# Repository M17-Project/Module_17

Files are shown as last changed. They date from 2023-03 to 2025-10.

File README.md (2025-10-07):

# Module 17
Welcome to Module 17 repository!

This project provides a standalone modem that transforms any 9600 baud capable transceiver into an [M17](https://m17project.org/) compatible radio. It is based on a STM32F4 microcontroller and is designed to run the [OpenRTX](https://openrtx.org/) firmware. Audio and PTT connectivity is given through a "Kenwood 2 Pin" compatible connector (2.5 and 3.5mm audio jacks) or an [OHIS](https://ohis.org/) connector (this is **NOT** an internet connector). Power supply of 6 to 15 volts can be applied through a 5.5/2.5mm DC plug.

<p align="center">
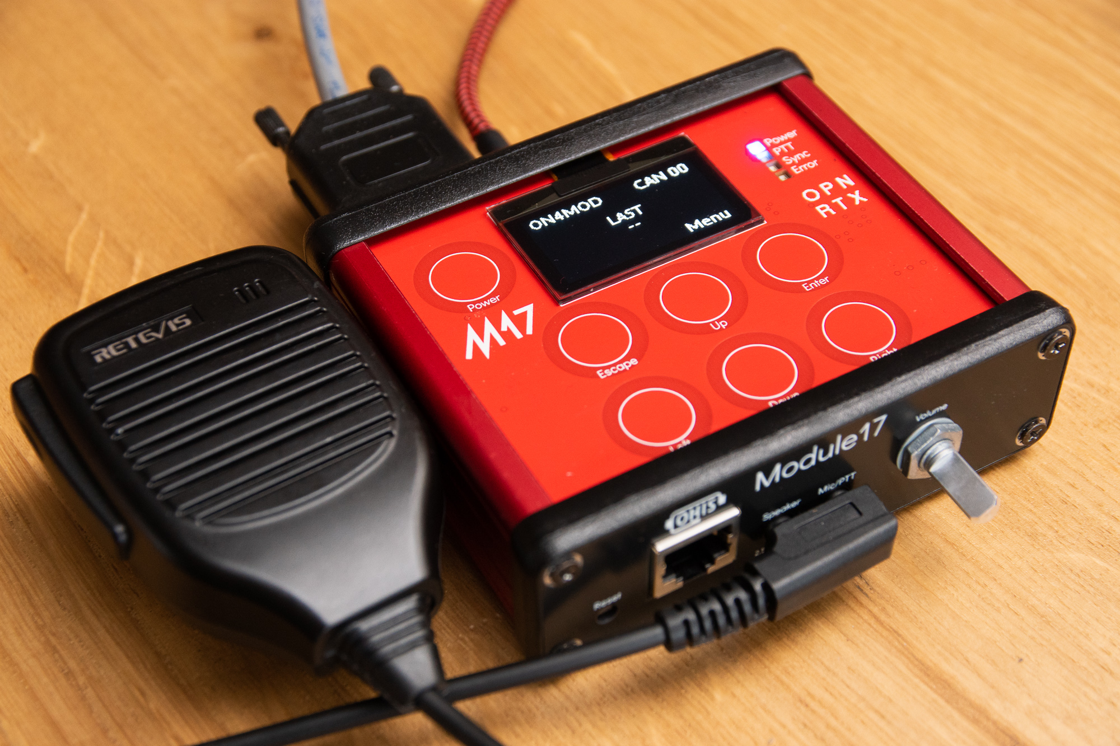
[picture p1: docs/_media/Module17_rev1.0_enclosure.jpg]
    
</p>

Several boards of various revisions have been built. The latest one is rev 1.0. This revision went through a complete board re-design, mainly to make it compatible with an aluminium extruded enclosure. It does however remain very similar in principle to the previous revisions. Other changes such as audio input and output improvements were made in this revision.

Revision 1.0 boards can be ordered partially or even fully assembled at [PCBWay](https://www.pcbway.com) with the manufacturing data in this repository. Some parts such as the digital potentiometers, the DC-DC converter inductor or the audio power amplifier may not (always) be in stock. Fortunately, they are almost always available through Mouser/Digikey. JLCPCB can acquire them through their global sourcing program if you are willing to use it.

## Versions
The current revision (rev 1.0) is available in two different versions:
- Enclosure with additional board for the user interface (called HMI, see picture above)
- Bare board (similar to how revisions 0.1d/e were used)
    <p align="center">
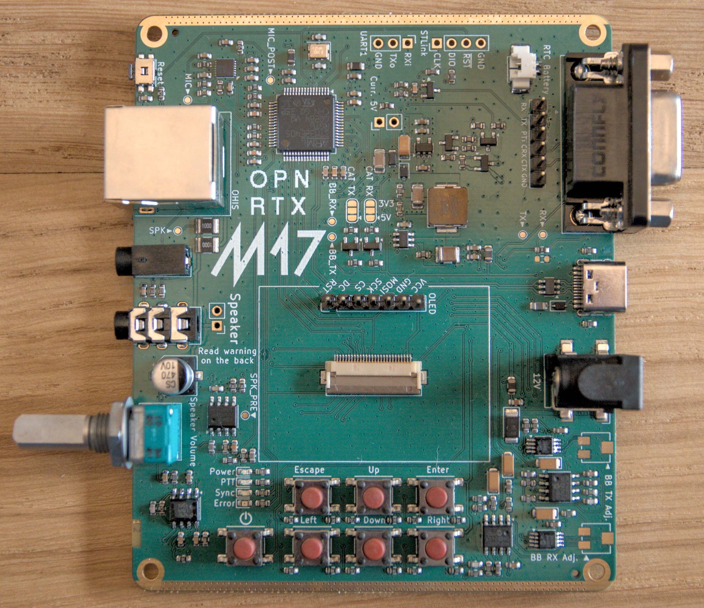
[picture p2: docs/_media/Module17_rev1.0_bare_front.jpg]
    
    </p>

The board can be switched from one version to another relatively easily. To convert a bare board to an enclosed version, the screen needs to be removed and a few additional PCBs need to be ordered (see the [Ordering guide](./docs/order.md)).

You can of course always 3D-print an enclosure for your bare board.

## Getting Started
The very first step is to get a board. The board is not available for sale yet. Head over to the [Ordering guide](./docs/order.md) to get a board. If you want to assemble the board with the designed enclosure and HMI, follow the instructions from the [enclosure instructions](./docs/enclosure.md).

Otherwise, if you just obtained a Module17 board, you may want to:

1. Flash it with OpenRTX, the officially supported firmware [Details](./docs/flashing.md)
2. Configure OpenRTX settings [Details](./docs/quickstart.md#configure-openrtx)
3. Connect the board to a radio. The DE-9 connector at the top of the board can be used to connect Module17 to a 9600baud radio. The pinout is shown in the table [here](./docs/features.md#de-9-connector).
4. Adjust the baseband levels for your specific transceiver [Details](./docs/quickstart.md#adjusting-the-baseband-levels)

A list of tested transceivers is [here](https://wiki.m17foundation.org/index.php?title=Radio_compatibility_list).

## Building the firmware yourself
Building instructions are available [at the OpenRTX project's website](https://openrtx.org/#/compiling).

## Features
The board contains many features, some of which you may never use. Here is a list:
- [Rev 1.0](./docs/features.md)
- [Rev 0.1d/e](../1e29440208ae519b9b4e89094e34ecb27943ad3d/README.md#usage-rev-01de)

## Acknowledgments
This project is inspired by David Rowe's [SM1000](https://www.rowetel.com/wordpress/?p=3125) "smart microphone".

## License
Module 17 hardware is licensed under the [CERN Open Hardware License - Weakly Reciprocal](https://ohwr.org/cern_ohl_w_v2.txt)

Module 17 is certified by OSHWA under ID BE000019.

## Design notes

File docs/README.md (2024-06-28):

# Module 17
Welcome to Module 17!

This project provides a standalone _smart microphone_ that transforms any 9600 baud capable transceiver into an [M17](https://m17project.org/) compatible radio. It is based on a STM32F4 microcontroller and is designed to run the [OpenRTX](https://openrtx.org/) firmware. Audio and PTT connectivity is given through a "Kenwood 2 Pin" compatible connector (2.5 and 3.5mm audio jacks) or an [OHIS](https://ohis.org/) connector (this is **NOT** an internet connector).

:size=25%

Several boards of various revisions have been built. The latest one is rev 1.0. This revision went through a complete board re-design, mainly to make it compatible with an aluminium extruded enclosure. It does however remain very similar in principle to the previous revisions. Other changes such as audio input and output improvements were made in this revision.

Revision 1.0 boards can be ordered partially or even fully assembled at [JLCPCB](https://www.jlcpcb.com) with the manufacturing data in this repository. Some parts such as the digital potentiometers, the DC-DC converter inductor or the audio power amplifier may not (always) be in stock at JLCPCB. Though they are almost always available through Mouser/Digikey. JLCPCB can acquire them through their global sourcing program if you are willing to use it.

## Acknowledgments
This project is inspired by David Rowe's [SM1000](https://www.rowetel.com/wordpress/?p=3125) Codec2 smart mic and shares some of its circuitry. The analog baseband filtering is inspired by the [MMDVM_RPT_Hat](https://github.com/mathisschmieder/MMDVM_RPT_Hat) and is a simplified version of F0DEI's original filter design that is used with great success at many MMDVM repeater sites.

## License
Module 17 is licensed under the [TAPR Open Hardware License](https://tapr.org/the-tapr-open-hardware-license/)

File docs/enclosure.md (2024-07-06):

## Enclosure

Module17 revision 1.0 is designed to be compatible with Hammond enclosures (model 1455L801).

### Hardware needed
To use Module17 with the enclosure, you need:
* One Module17 revision 1.0
* One Hammond 1455L801 enclosure (you do not need the sliding plate or the end panels)
* One Module17 HMI board revision 1.0
* One flex 26 pins flex connector (FFC cable, pitch of 0.5mm, connectors thickness of 0.3mm, length of minimum 50mm, edge connectors on the same side)
* One of each side panel PCB
* One 128x64 OLED screen (1.54" diagonal, SSD1309 driver)
* Optional: 8 self-tapping screws with non-tapered head (one standard that might fit is DIN 7500 with size M3.5). This is optional as the screws that came with the enclosure can be used, but the side panels PCBs do not have tapered holes so the fit will not be perfect.

### Assembly instructions
1) First open the enclosure, removing the end panels and removing the sliding plate.
2) Connect the mainboard to the HMI board using the FFC cable: one end of the cable goes in the FFC connector placed below the screen connector, the other end in the FFC connector on the left of the HMI board (when facing the side with the components). The connectors of the cable must face the boards for each connector.
3) Carefully slide the mainboard and the HMI inside the enclosure. The mainboard goes in the lowest position. The HMI board slides at the place where the sliding place removed at step 1 was located.
4) Insert the side panels PCBs inside the plastic bezels that came with the enclosure.
5) Place the side panels on the assembly and screw then in place.
6) Stick the rubber feets that came with the enclosures on the bottom of the assembly.

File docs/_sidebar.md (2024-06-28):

* [Home](/)
* [README](./README.md)
* [Flashing](./flashing.md)
* [Features](./features.md)
* [Ordering](./order.md)
* [Enclosure](./enclosure.md)
* [Revisions](./revisions.md)

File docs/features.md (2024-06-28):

# Features (rev 1.0)

<p align="center">
    
</p>

## Power supply

The modem can be supplied with:
- a 6..15V source via the DC plug (left of the USB-C socket) or pin 9 of the DE9 connector (upper right hand side),
- 5V through the USB-C connector (in the middle of the right side)
Both inputs can be used at the same time.

When power is supplied through the barrel jack (DC plug) the board can be powered on using the power button and powered off in the menu of the board (Enter -> Select Shutdown -> Enter)

When power is supplied through the USB-C socket, the board is always powered on and cannot be powered off.

## DE-9 connector

The DE-9 connector at the top of the board can be used to connect Module17 to a 9600baud radio. The pinout is shown in the table below.

| Pin | Function | Direction | `CT-167` cable wire color |
|---|:---:|---|---|
| 1 |  unused (floating) |  -- | |
| 2 |  baseband output (towards radio) |  output |  brown |
| 3 |  CAT-RX |  input | |
| 4 |  CAT-TX |  output | |
| 5 |  radio PTT |  output, open-drain, low-active  |  red |
| 6 |  baseband input (from radio) |  input |  orange |
| 7 |  unused (floating) |  -- | |
| 8 |  ground |  -- |  black, thick |
| 9 |  12V input | input (supply) | |

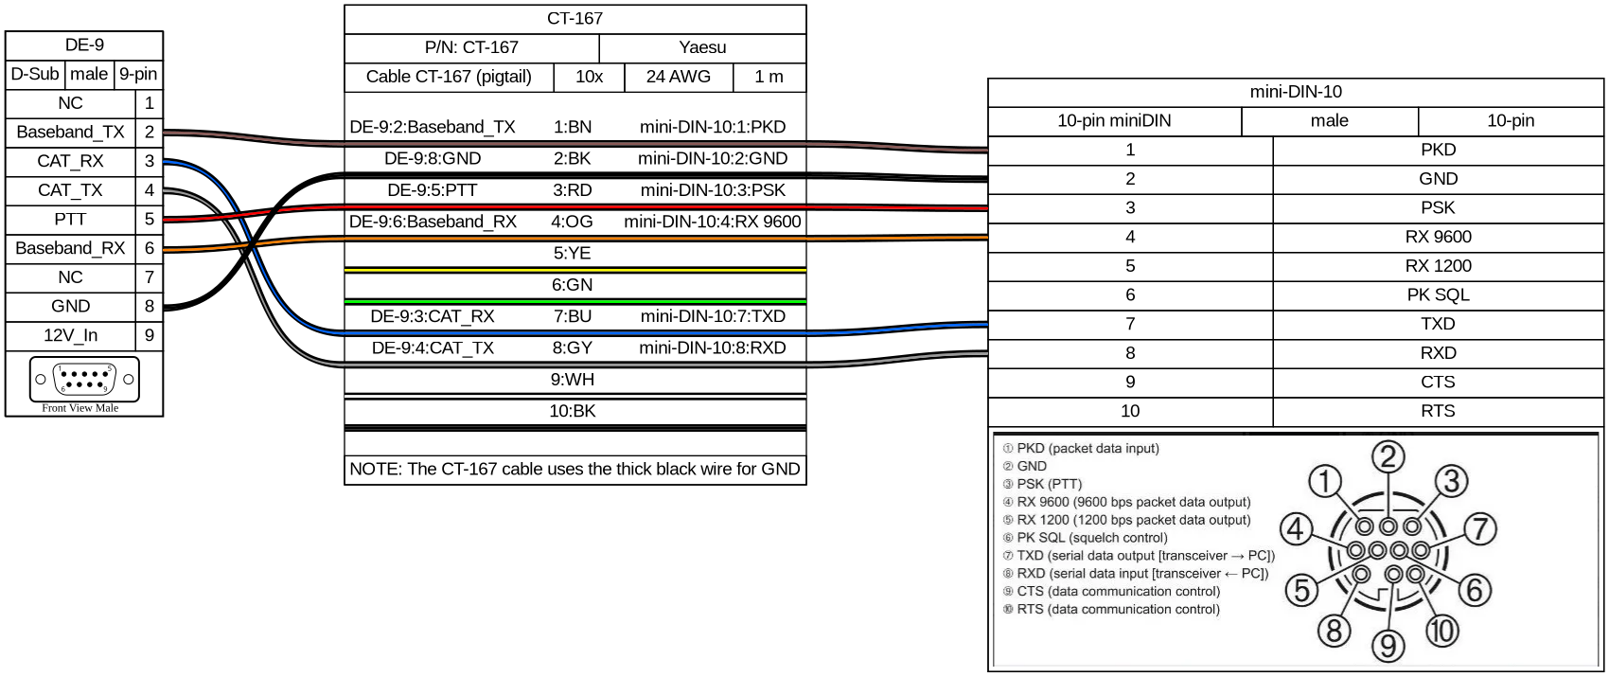
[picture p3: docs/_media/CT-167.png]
CT-167 Wiring :size=75%


Additionally, there is a 2.54mm pin header just next to the DE-9 connector that can be used for convenient access to the baseband, PTT and CAT signals. Pin 9 doesn't have to be used, it only provides an alternative way for supplying power to the board.  

## Kenwood mic-speaker connector

On the left hand side of the board, there is a Kenwood-type connector. The pinout is standard and most microphone-speakers should be compatible with Module17. In particular, the microphone-speakers from Baofeng, TYT and Retevis have been tested and are compatible.

## OHIS connector

The board provides an OHIS connector if you want to use other audio devices than classical microphone-speakers. The connector does not provide the optional 5V output. See [OHIS Website](https://ohis.org/) for more information.

## Volume knob

The volume knob is at the bottom left part of the board. As the name suggests, it is used for audio volume setting. 

## Transmission/reception

At idle, the device will look for valid M17 signal in the baseband. If there is a valid signal detected carrying voice data, it will be decoded and sent to the speaker outputs at the Kenwood  connector. There is also an additional, unpopulated, 2-pin speaker connector in the left part of the modem. It can be used to connect an external >=8ohms speaker.
Transmission is triggered by the PTT key of the mic-speaker or OHIS connector. A valid baseband signal along with a PTT signal is then sent to the radio.

## Baseband tuning

In order to support as many transceivers as possible, the baseband level requires tuning to drive your transceiver with the correct signal level. The process depends on the variant of your board. If you have the digital potentiometers fitted, the adjustment is done in OpenRTX. If you have the multiturn potentiometers fittes, you will need to adjust them using a small screwdriver. The detailed procedure is explained

## CAT control

The hardware is ready for CAT signal to control a transceiver using the modem but OpenRTX does not implement it yet. It can not be used out of the box and you would need to implement it manually to use it. There is hardware support for logical level selection (3.3V or 5V). (June 2024)

## RTC Battery

The hardware has a microblade connector to enable you to connect a 3V lithium battery to supply the real time clock inside the microcontroller. OpenRTX does not implement RTC management for Module17 yet. (June 2024)

## Test points

Multiple test points are available on the PCB to allow you to check the values of all the various signals (audio, baseband, power supplies, ...). Those are labeled with the signal they expose.

## Debug port

A debug port is available on the top part of the modem. It exposes the signals for the ARM SWD port of the microcontroller.

## Serial port

A serial port is exposed on the top part of the modem. It allows you to, for example, add a GPS chip (there is currently no software support for GPS). (June 2024)

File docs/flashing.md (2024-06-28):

## Flashing

### Entering DFU mode
To flash the board, you need to put it in DFU mode. The procedure to do so will depend whether you use the HMI board or not.

#### Using the bare modem board (rev 1.0)
Hold the "Escape" (upper left) button down while pressing the reset switch (upper left corner of the board) or plugging in the USB cable.

#### Using the HMI and enclosure (rev 1.0)
First put the switch on the rear of the device to the "FW Update" position then either plug in the USB cable or press the reset switch (bottom left corner of the front face of the device). When the device is in DFU mode, you can then put the switch on the rear of the device back to the "Run" position.

#### Using the bare modem board (revisions 0.1a to 0.1e)
Hold the "Escape" (upper left) button down while pressing the reset switch (left side of the board, above the kenwood connectors) or plugging in the USB cable.

### Linux
To flash, you first need to put the device in DFU mode (see above).

You need `dfu-util` 0.11 to start the process. `dfu-util` installation instructions are [here](https://dfu-util.sourceforge.net/build.html). It is recommended to use the most recent version - built from source.

For your convenience, a pre-built binary is available [here](https://files.openrtx.org/nightly/) and [here](https://openrtx.schinken-radio.de/nightly/). The name of the file is `openrtx_mod17_wrap`.
You can then follow standard [OpenRTX](https://github.com/OpenRTX/OpenRTX)
flashing instructions for the "mod17" target if you have dfu-util
installed:<br>
`dfu-util -d 0483:df11 -a 0 -D openrtx_mod17_wrap -s 0x08000000`

Once flashing is complete, reset the board to boot into the newly flashed application. If there are any errors while flashing, make sure there's a valid udev rule available for the Module17. Download the [udev](https://github.com/OpenRTX/OpenRTX/blob/master/99-openrtx.rules) file and then run the following commands:<br>
`sudo cp 99-openrtx.rules /etc/udev/rules.d`<br>
`sudo udevadm control --reload-rules`.

### Windows
To flash, you first need to put the device in DFU mode (see above).

Be sure that you have WinUSB installed for your DFU device. You can use [Zadig](https://zadig.akeo.ie/). After the Module17 is connected and in DFU mode, select it from the list in Zadig, then install the driver.

- Download the [dfu-util-0.11-binaries.tar.xz dfu-util binary for Windows](https://dfu-util.sourceforge.net/releases/) and unzip.
- Download the `openrtx_mod17_wrap` file, it's available [here](https://files.openrtx.org/nightly/) and [here](https://openrtx.schinken-radio.de/nightly/).
- Navigate to `{extraction_location}\dfu-util-0.11-binaries\win64` (or `win32`) and copy the wrap file there. Example path: `C:\Users\SP5WWP\Desktop\dfu-util-0.11-binaries\win64`.
- Run the command prompt (`cmd`) as administrator and change the working directory with `cd {extraction_location}\dfu-util-0.11-binaries\win64`.
- Run the following command: `dfu-util -d 0483:df11 -a 0 -D openrtx_mod17_wrap -s 0x08000000`
- After the flashing is complete, close the command prompt and reset the device.

### Building the firmware yourself
Building instructions are available [at the OpenRTX project's website](https://openrtx.org/#/compiling).<br>

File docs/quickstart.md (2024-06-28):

# Quickstart guide

You have successfuly [flashed](./flashing.md) your Module17 and want to get started? This quickstart guide explains how to get on the air for the first time.

## Configure OpenRTX

The first thing to do is to configure OpenRTX. The only real change needed is to encode your callsign in the device. For that:
- Press "Enter"
- Select "M17" and press "Enter"
- Select "Callsign" and press "Enter"
- Input your callsign using "Up"/"Down" to select the correct letter and "Left/Right" to muve the cursor to the left/right. 
- Press "Enter" once you are done.

## Adjusting the baseband levels

### Check your transceiver compatibility

[This wiki page](https://wiki.m17project.org/radio_compatibility) contains a non-exhaustive list of the known compatible transceiver. Check if yours is in the list. If it is not, you will need to test it. Please submit an issue [here](https://github.com/M17-Project/wiki/issues) once you are done testing your radio.

### Adjust the baseband level

The precise level of the baseband signal needs to be tuned to your radio's requirements. You will need to adjust both the RX and TX levels separately.

Depending on the variant of your board, the level tuning is done with digital potentiometers or multiturn potentiometers. 

The multiturn potentiometers need to be adjusted with a small screwdriver.

The digital potentiometers need to be adjusted from within OpenRTX. For that, power-up your Module17 and:
- Press "Enter"
- Select "Settings" and press "Enter"
- Select "Module17" and press "Enter"
- Select the baseband signal you want to adjust. Adjust the level using the "Left"/"Right" keys.

#### Adjusting TX level

The most reliable way to tune the TX baseband signal level is using SDR++ and an SDR receiver (like an RTL-SDR). 

- Connect your Module17 to your radio
- Add an M17 demodulator module to your SDR++ interface and tune it to the frequency of your radio
- In the m17_decoder module you added, tick the "Show Reference Lines" box
- While pressing the PTT, have a look at the symbols graph of the m17\_decoder module and adjust the baseband TX level until the blue dots line-up with the gray lines in the background
- When the baseband level is properly adjusted, the m17_decoder should correctly decode your signal. If it does not, check your TX baseband polarity. If it still does not work, your radio may be incompatible.

#### Adjusting RX baseband level

A proper RX baseband level adjustment is not as crucial as for TX baseband. You should set it so that the peak-to-peak voltage of the RX baseband signal (on testpoint labeled `BB_RX`) is right under 3.3V. Anything above that means that the signal will be saturating in the MCU. Anything below that means that you are not using the full dynamic range of the analog-to-digital converter.

In order to measure the level on the testpoint, you can use an oscilloscope if you have one. You can also use a digital multimerer (but pay attention that the value displayed will **NOT** be the peak-to-peak voltage but the RMS voltage; in that case aim vor an RMS value of 1.1V). You should measure this voltage while receiving an M17 baseband signal.

If the signal is tuned to the proper level but the board cannot demodulate the incoming signal then check the RX baseband signal polarity. If it still does not work, then your radio may be incompatible.

### Adjust the baseband polarity

The polarity of the baseband signal may need to be modified depending on your specific radio. If your radio is listed in the compatibility list linked above then you can re-use the settings from that list. Otherwise you will need to try both settings for RX and TX to check which one works.

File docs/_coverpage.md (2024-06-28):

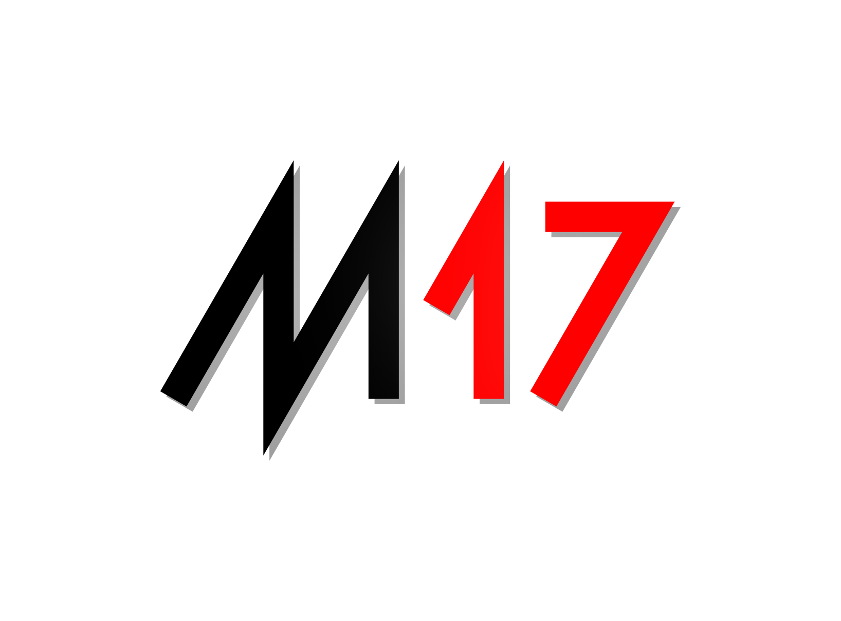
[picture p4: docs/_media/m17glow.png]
:size=25%


# Module 17 <small>1.0</small>

> A smart-mic for the M17 Protocol

[Github](https://github.com/M17-Project/Module_17)
[Get Started](README)

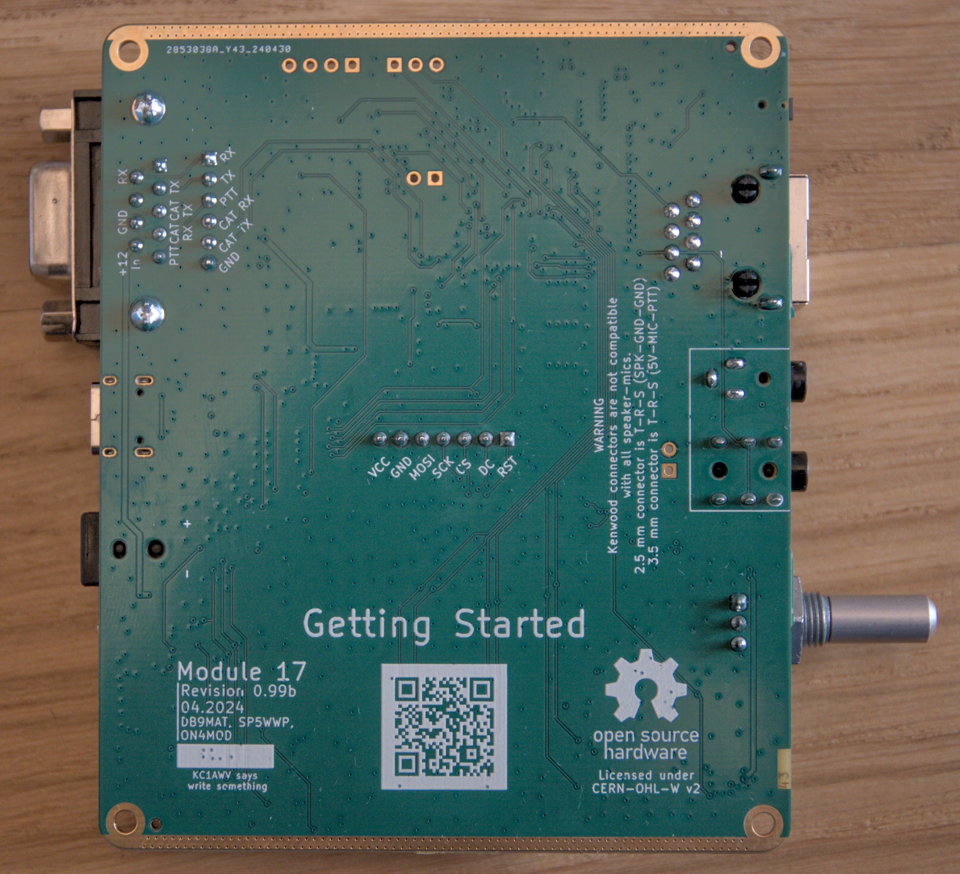
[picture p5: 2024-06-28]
docs/_media/Module17_rev1.0_bare_back.jpg

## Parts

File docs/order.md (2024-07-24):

# Ordering guide for Module17

This guide explains how to order Module17 boards on JLCPCB. JLCPCB is one of the websites that provides PCB assembly services to customers in small series. Other websites do provide the same services and you would have to adapt those instructions (though the general process will stay the same).

The process to order the board is quite simple :
- You upload the manufacturing files to the manufacturers website
- You configure the order to produce the boards correctly
- You upload a list of components and their positions on the board
- You fix the components placement and the parts numbers
- You receive the boards (and solder a few additional components if needed)

The first four steps have to be repeated for each board that you want to order. You will usually order the mainboard in all cases. You can additionally order the HMI and front/back panels if you want to use the [designed enclosure](./enclosure.md). The side panels only require the first two steps as they do not contain any components.

If you want to use the bareboad version with only the mainboard, you will also need an additional screen from Waveshare ([Waveshare 18179](https://www.waveshare.com/1.3inch-oled-module-c.htm))

## Production files

You will first need to locate the production files as you will have to upload them on JLCPCB website. 

* Mainboard files are located in [`Module_17/hardware/mainboard/production/`](../hardware/mainboard/production):
    * [`Module17_Rev_1.0.zip`](../hardware/mainboard/production/Module17_Rev_1.0.zip) contains the gerber files (the PCB fabrication files)
    * [`bom_digipot.csv`](../hardware/mainboard/production/bom-digipot.csv) contains the bill-of-materials, the list of components needed
    * [`positions_digipot.csv`](../hardware/mainboard/production/positions-digipot.csv) contains the position of all the components to assemble on the board (also called CPL file)

    Note: Both the BOM and positions files have a `-multiturn` variant that is to be used if you want to use the multiturn potentiometers for the baseband tuning instead of the digital potentiometers (see [below](./order.md#mainboard))

* HMI files are located in [`Module_17/hardware/HMI/production/`](../hardware/HMI/production):
    * [`Module17_HMI_Rev_1.0.zip`](../hardware/HMI/production/Module17_HMI_Rev_1.0.zip) contains the gerber files (the PCB fabrication files)
    * [`bom.csv`](../hardware/HMI/production/bom.csv) contains the bill-of-materials, the list of components needed
    * [`positions.csv`](../hardware/HMI/production/positions.csv) contains the position of all the components to assemble on the board (also called CPL file)

* Side panels files are located in [`Module_17/hardware/side_panels/production/`](../hardware/side_panels/production):
    * [`Module17_HMI_Front_Panel_Rev_1.0.zip`](../hardware/side_panels/production/Module17_HMI_Front_Panel_Rev_1.0.zip) contains the gerber files for the front panel
    * [`Module17_HMI_Back_Panel_Rev_1.0.zip`](../hardware/side_panels/production/Module17_HMI_Back_Panel_Rev_1.0.zip) contains the gerber files for the back panel

## Ordering

For each board that you want to order, follow the following instructions. Additional, **important** board-specific instructions are provided below. 

- Navigate to [https://cart.jlcpcb.com/quote](https://cart.jlcpcb.com/quote) 
- Click on "Add gerber file" and upload the zip file containing the gerber files (PCB fabrication files)
- Once the files are uploaded, ensure the correct settings are selected for the board you are ordering (the settings differ for the main board, HMI and side panels, see below)
- If you selected the "PCB Assembly" option, click next, otherwise, click "Save to cart" and you are done

The following instructions are for PCB Assembly:
- Select the "Bill of Materials" tab above the picture of the PCB
- Click "Add BOM File" and select the `bom.csv` file corresponding to the board you are ordering
- Click "Add CPL File" and select the `position.csv` file corresponding to the board you are ordering
- Click "Process BOM & CPL"
- ***VERY IMPORTANT:*** check that the correct components are selected by JLCPCB. You will most probably need to do a few adjustments (see below for board-specific instructions)
- Click Next. If JLCPCB shows a pop-up saying "Project has unselected parts" click "Do not place". If you did not intend to order the board with these parts then it is alright. Otherwise, you will need to order those parts elsewhere and solder them by hand once you received the partially assembled boards
- If JLCPCB then says that "The system detects component that may be offset from the PCB" click "Ok"
- Carefully check that all the components on the board are placed correctly. See the instructions below for an example picture
- Click "Next" and check the overview of you order
- Click "Save to Cart"

# Board-specific instructions

## Mainboard

The mainboard is the core part of Module17. They are several variations that are possible:

* **Digital potentiometers vs multiturn potentiometers**: Depending on your preferences and/or the parts availability, you may want to choose digital potentiometers (configured at runtime in OpenRTX) or the multiturn potentiometers. The performances of the board will be the same anyway

* **If you do not plan on using the bare motherboard** i.e. if you only plan to use the board with the designed enclosure and HMI, you can choose not to assemble the following components to reduce the cost:
    - J406
    - SW202-208
    - D204-207

* **If you do not plan on using the designed enclosure and HMI**: you can choose not to assemble the following component:
    - J412

* Depending on the [features](./features.md) that you want, you may wish to assemble (or not) the following components:
    - J413 for the RTC
    - J408 for the STLink debugger
    - J409 for the UART 
    - J403 to break out the signals from the packet-radio connector

### PCB settings

It is recommended to order the PCB by selecting the following parameters:
- PCB Color: Green will usually be the cheapest and fastest option. But feel free to chose any other color you want.
- Material Type: FR-4 TG155
- Surface Finish: ENIG
- Remove Order Number: Specify a location
- PCB Assembly: tick the box (given the number of components and their size, it is highly recommended to let JLCPCB assemble the board. Assemble it yourself only if you know what you are doing)
    - Select "Assemble top side"
    - PCBA Type: Economic (if you can not select Economic, then the color you have chosen may be incompatible with the Economic option. This will result in an increased price but the rest of the process stays the same)

### Bill of Material

It is advised to pay attention to these components when ordering:

* The components selected for some of the **10 nF capacitors** (C304, C315, C503, C505, C506, C508), the **680pF capacitors** (C504, C509) and **1.5nF capacitor** (C303) can be matched by JLCPCB with components using X7R dielectric. It is advised to use C0G dielectric capacitors. You can search for components by appending "0603 COG" to the value of the component (example: "10nF 0603 C0G" will list compatible 10nF capacitors using C0G dielectric).

* **The LEDs** (D204-207) are pre-populated by JLCPCB with RED leds. You should change the components selected for the blue (power), green (sync) and orange (error) LEDs. You can use components from the KT-0603 series (KT-0603R, KT0603B,...). The last letter refers to the color of the LED.

* Check that the **crystal** pre-populated by JLCPCB is designed to run with a 12pF capacitive load. Make sure to pick a crystal with a tolerance of 10ppm. You can use the keywords "8MHz 12pf SMD3225 10ppm" for the search.

* The tactile switches pre-selected in the BOM may not be available. You can pick another switch from the PTS645 series of surface-mount tactile switches (PTS645-S-\*-\*\*-SMTR92) using the keywords "PTS645S SMTR92". This can also help reduce the cost of the BOM depending on the prices at the time of ordering.

* D203, D401 are supposed to be BAT60A diodes but those can sometimes be hard to find. You can replace those with other low-Vf Schottky diodes, most notably the 1N5819WS (JLCPCB ID: C191023) is a basic part at JLCPCB (no additional fees) that is easily available.

* U501, U502 are the digital potentiometers for the baseband filters. If those are not available, you can either opt for the version with multiturn potentiometers, or order those components somewhere else. They are not that hard to solder by hand

* IC301 is the audio power amplifier. This can be ordered somewhere else and assembled by hand.

### Components placement

Here is a picture of the components placement on a board ready to be ordered:
    <p align="center">
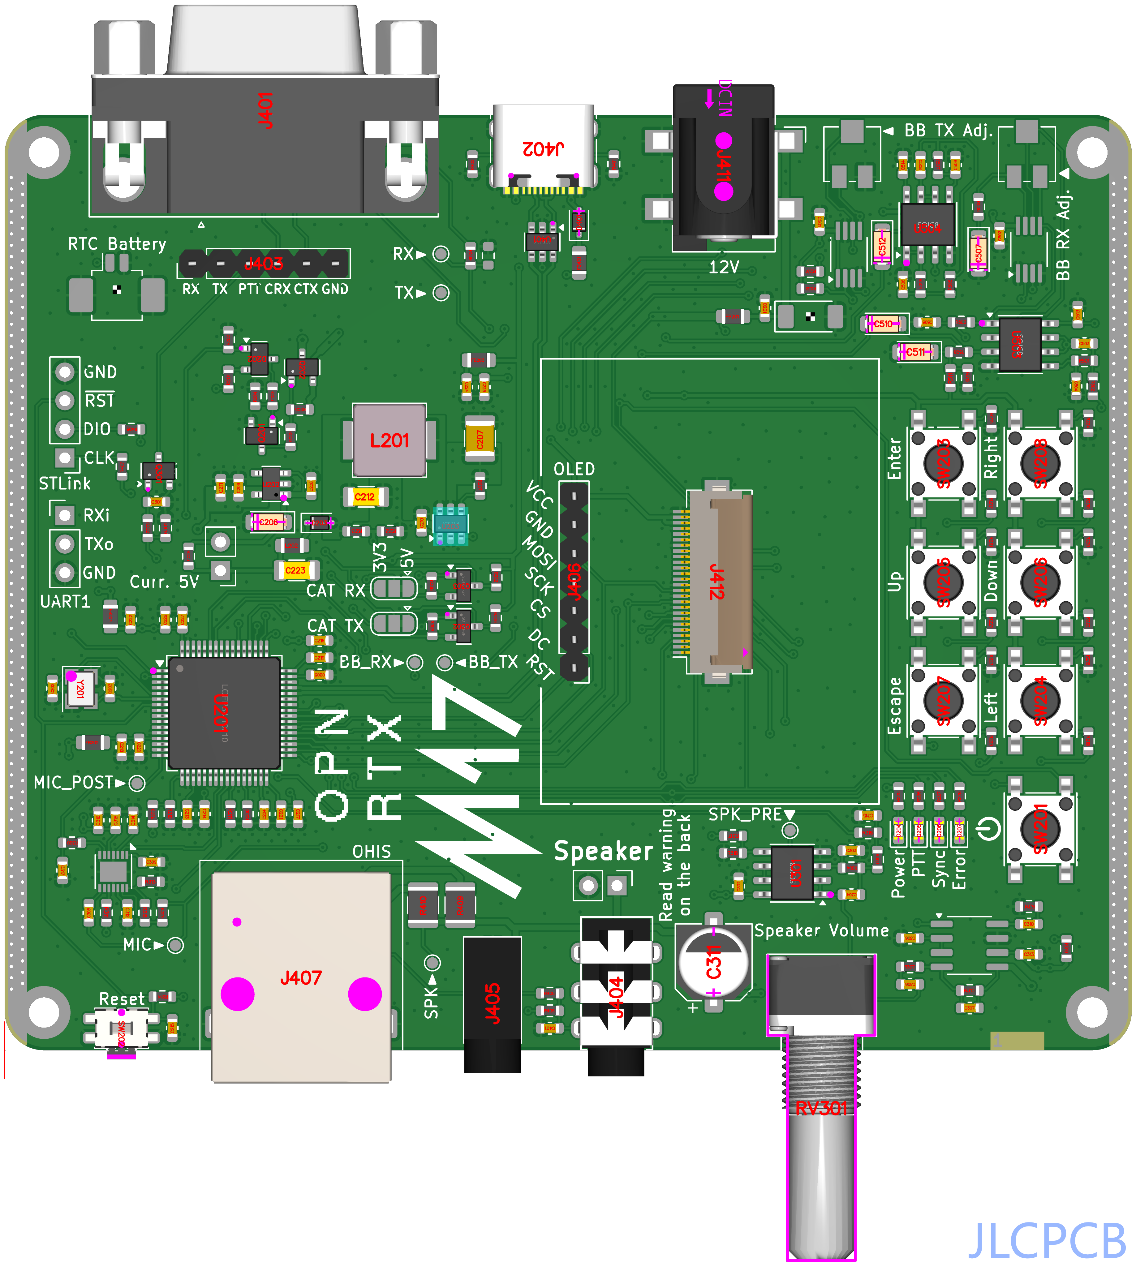
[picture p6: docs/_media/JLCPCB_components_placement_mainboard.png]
        
    </p>

Some of the big components may be visibly offset/rotated from their intended positions. But some smaller components may also be rotated from their intended position. To check that, make sure that the small white triangle printed on the board matches the pink dot in the corner of the component.

## HMI

The HMI is the additional user interface that will slide in the enclosure and contains the screen, LEDs and capacitive (tactile) switches.

### PCB settings

It is recommended to order the PCB by selecting the following parameters:
- PCB Color: Red will usually be the nicest-looking option. But feel free to chose any other color you want.
- Material Type: FR-4 TG155
- Surface Finish: "HASL (with lead)" is the cheapest option. You can select any other option if you wish.
- Via covering: "Epoxy Filled & Capped" will make the board look much nicer. You can choose "Plugged" if you want to spare a few bucks, but beware that the board will be riddled with tiny holes. 
- Remove Order Number: Specify a location
- PCB Assembly: tick the box (given the number of components and their size, it is highly recommended to let JLCPCB assemble the board. Assemble it yourself only if you know what you are doing)
    - Select "Assemble **bottom** side"
    - PCBA Type: Standard (at the time of writing, JLCPCB does not support Economic assembly for 4-layers board that are any other color than Green. If this option is available to you at the time of ordering, then select Economic to save a bit of money)

### Bill of Material

It is advised to pay attention to these components when ordering:

* R1 is often matched to a 1.3 Mohm resistor instead of a 1.37 Mohm resistor.

* D1 is supposed to be a BAT60A diode but those can sometimes be out-of-stock. You can replace it with other low-Vf Schottky diodes, most notably the 1N5819WS (JLCPCB ID: C191023) is a basic part at JLCPCB (no additional fees) that is easily available.

* SW9 is often out-of-stock. This component can be ordered somewhere else and soldered by hand.

* U4 can sometimes be matched with another (incompatible) reference. Check that the reference selected for this component is CAP1206-1-SL. If not, change it. It may also not be in stock at JLCPCB and you may need to order it elsewhere. It is easy to solder by hand.

* U3 is not part of JLCPCB's catalog (at least at the time of writing this). You will have to ordered it somewhere else. It can easily be soldered by hand (full parts numbers: IQS211B00000000TS).

### Components placement

Here is a picture of the components placement on a board ready to be ordered:
    <p align="center">
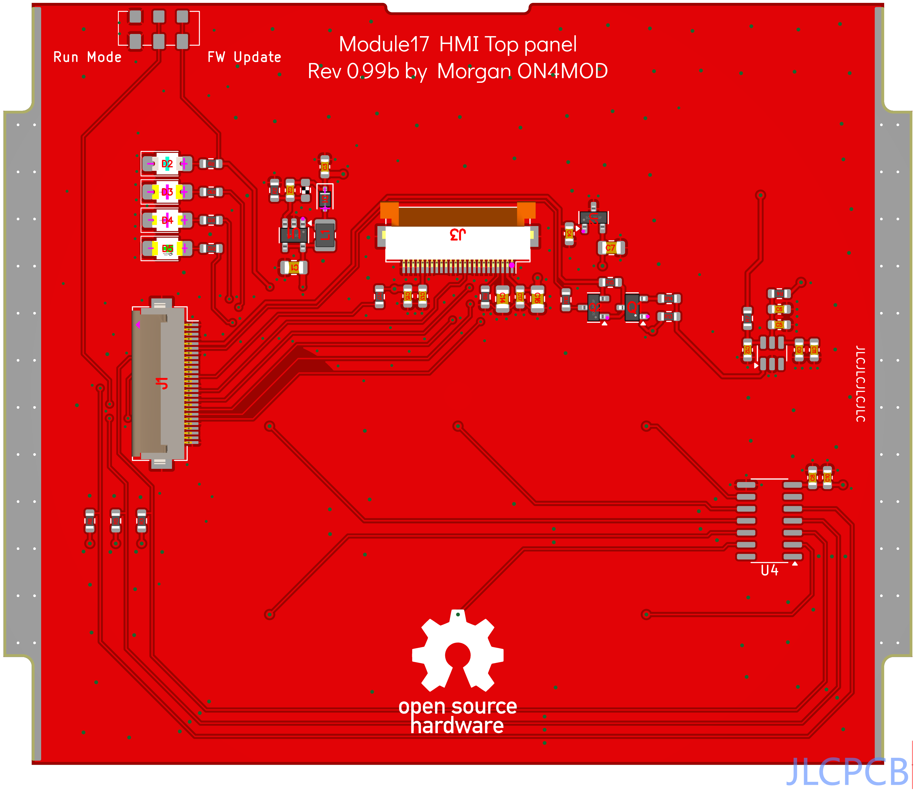
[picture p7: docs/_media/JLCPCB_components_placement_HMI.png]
        
    </p>

You may need to select the bottom side of the board in the top right corner of the GUI.
Some smaller components may be rotated from their intended position (the LEDs are often mounted in the wrong way (top-left corner)). To check that, make sure that the small white triangle printed on the board matches the pink dot in the corner of the component. For the LEDs the '-' of the component should be on the side of the "inside" of the "U" painted around the component.

## Side panels

The side panels are smaller boards that are used as front and back plates.
No components are mounted on those boards.

### PCB Settings

It is recommended to order the PCB by selecting the following parameters:
- PCB Color: Black will usually be the nicest-looking option. But feel free to chose any other color you want.
- Remove Order Number: Specify a location

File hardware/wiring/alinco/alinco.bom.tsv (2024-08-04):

Id | Description | Qty | Unit | Designators | P/N | Manufacturer
1 | Cable, 4 x 24 AWG shielded | 1 | m | Cable | 9534 | Belden
2 | Connector, D-Sub, male, 9 pins | 2 |  | to Alinco, to Module17

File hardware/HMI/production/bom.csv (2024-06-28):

Designator | Footprint | Quantity | Value | LCSC Part #
C1, C16 | 0805 | 2 | 4u7
C10, C11, C13, C15, C3, C4, C5 | 0603 | 7 | 1u
C12 | 0603 | 1 | 10p
C14 | 0805 | 1 | 2u2
C17, C8 | 0603 | 2 | 100n
C2 | 0603 | 1 | 15p
C6, C9 | 0603 | 2 | 100p
C7 | 0805 | 1 | 10u
D1 | D_SOD-323 | 1 | BAT60A
D2 | LED_LiteOn_LTST-C230 | 1 | Blue | C125109
D3 | LED_LiteOn_LTST-C230 | 1 | Red | C125107
D4 | LED_LiteOn_LTST-C230 | 1 | Green | C125106
D5 | LED_LiteOn_LTST-C230 | 1 | Yellow | C125108
J1 | Hirose_FH12-26S-0.5SH_1x26-1MP_P0.50mm_Horizontal | 1 | Hirose FH12-26S-0.5SH(55) | C202113
J3 | Hirose_FH12-24S-0.5SH_1x24-1MP_P0.50mm_Horizontal | 1 | Hirose FH12A-24S-0.5SH(55) | C506794
L1 | 1008 | 1 | 1uH
Q1 | SOT-23 | 1 | MMBT3904
Q2 | SOT-23 | 1 | BSS84
R1 | 0603 | 1 | 1M37
R10, R11, R12, R16, R9 | 0603 | 5 | 680R
R13, R14, R15, R17 | 0603 | 4 | 10k
R2 | 0603 | 1 | 150k
R3, R5, R6 | 0603 | 3 | 1k2
R4 | 0603 | 1 | 40.2
R7 | 0603 | 1 | 470R
R8 | 0603 | 1 | 953k
SW9 | Nidec_Copal-SB-22A_edge | 1 | CL-SB-22A-11T
U1 | SOT-23-5 | 1 | TPS61040DBV | C7722
U2 | SOT-23 | 1 | AP7375-33SA | C5944186
U3 | TSOT-23-6 | 1 | IQS211B00000000TS
U4 | SOIC-14_3.9x8.7mm_P1.27mm | 1 | CAP1206-1-SL

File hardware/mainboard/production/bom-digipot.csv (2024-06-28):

Designator | Footprint | Quantity | Value | LCSC Part #
C201, C214, C219, C221, C227 | 0603 | 5 | 10n | Generic C/10nF/X7R/25V/0603
C202, C203 | 0603 | 2 | 12p | Generic C/12pF/C0G/16V/0603
C204, C205, C314, C318 | 0603 | 4 | 2u2 | Generic C/2.2uF/X5R/25V/0603
C206 | CP_EIA-3216-18_Kemet-A | 1 | 10u | C110055
C207 | 1210 | 1 | 10u | Generic C/10uF/X7R/25V/1210
C208, C209, C210, C213, C215, C216, C217, C220, C225, C226, C302, C306, C308, C309, C310, C313, C316, C317, C401, C501, C502, C513, C514 | 0603 | 23 | 100n | Generic C/100nF/X7R/50V/0603
C211, C218, C222, C224 | 0603 | 4 | 1u | Generic C/1uF/X7R/25V/0603
C212, C223 | 1206 | 2 | 22u | Generic C/22uF/X7R/10V/1206
C301 | 0603 | 1 | 470p | Generic C/470pF/C0G/25V/0603
C303 | 0603 | 1 | 1n5 | Generic C 1n5/X7R/10V/0603
C304, C315, C503, C505, C506, C508 | 0603 | 6 | 10n | Generic C/10nF/C0G/25V/0603
C305 | 0603 | 1 | 220n | Generic C/220nF/X7R/25V/0603
C307 | 0603 | 1 | 15p | Generic C/15pF/C0G/25V/0603
C311 | CP_Elec_6.3x7.7 | 1 | 470u | C116423
C312 | 0603 | 1 | 470n | Generic C/470nF/X7R/50V/0603
C504, C509 | 0603 | 2 | 680p | Generic C/680pF/C0G/25V/0603
C507, C510, C511, C512 | CP_EIA-3216-18_Kemet-A | 4 | 22u | C118989
D201 | D_SOD-128 | 1 | PTVS18VP1UP | C2909295
D202 | SOT-23 | 1 | BAT54C | C2135
D203, D401 | D_SOD-323 | 2 | BAT60A | C520634
D204 | 0603 | 1 | Blue | Generic LED/Blue/0603
D205 | 0603 | 1 | Red | Generic LED/Red/0603
D206 | 0603 | 1 | Green | Generic LED/Green/0603
D207 | 0603 | 1 | Orange | Generic LED/Orange/0603
FB201, FB202, FB203, FB204, FB401 | 0805 | 5 | FB0805 | C1017
IC301 | SOIC-8_3.9x4.9mm_P1.27mm | 1 | LM4991MA | C2860134
J401 | DSUB-9_Female_Horizontal_P2.77x2.84mm_EdgePinOffset7.70mm_Housed_MountingHolesOffset9.12mm | 1 | Radio | C75749
J402 | USB_C_Receptacle_HRO_TYPE-C-31-M-12 | 1 | USB_C | C165948
J403 | PinHeader_1x06_P2.54mm_Vertical | 1 | Radio_Opt | C492405
J404 | PJ-3136-B | 1 | Kenwood-3.5 | C381131
J405 | PJ-211A | 1 | Kenwood-2.5 | C480265
J406 | PinHeader_1x07_P2.54mm_Vertical | 1 | 2.54mm Header 7p | C492406
J407 | KH-RJ45-58-8P8C | 1 | KH-RJ45-58-8P8C | C2683360
J411 | BarrelJack_CLIFF_FC681465S_SMT_Horizontal | 1 | +12V | C319133
J412 | Hirose_FH12-26S-0.5SH_1x26-1MP_P0.50mm_Horizontal | 1 | Hirose FH12-26S-0.5SH(55) | C202113
J413 | Molex_PicoBlade_53261-0271_1x02-1MP_P1.25mm_Horizontal | 1 | Molex 532610271 | C189700
L201 | L_Vishay_IHLP-2525 | 1 | 10u | C506573
L202 | 0805 | 1 | 1u | C223144
Q201 | SOT-23 | 1 | MMBT3904 | C84555
Q202 | SOT-23 | 1 | IRLML2244 | C169763
Q301 | SOT-23 | 1 | IRLML2060 | C67275
Q302, Q303 | SOT-23 | 2 | BSS138 | C400505
R201, R204, R207, R313 | 0603 | 4 | 100k | Generic R/100k/0603
R202, R203, R209, R210, R211, R215, R216, R219, R220, R223, R224, R305, R306, R308, R312, R317, R318, R319, R405 | 0603 | 19 | 10k | Generic R/10k/0603
R205, R206, R508, R511, R512 | 0603 | 5 | 22k | Generic R/22k/0603
R208 | 0603 | 1 | 1k | Generic R/1k/0603
R212 | 0603 | 1 | 8k2 | Generic R/8k2/0603
R213 | 0603 | 1 | 43k | Generic R/43k/0603
R214, R301, R310 | 0603 | 3 | 47k | Generic R/47k/0603
R217, R218, R221, R222, R229, R230 | 0603 | 6 | 470 | Generic R/470R/0603
R225, R226, R227, R228 | 0603 | 4 | 680 | Generic R/680R/0603
R231, R232, R309, R406, R506 | 0603 | 5 | 2k2 | Generic R/2k2/0603
R233, R311, R509 | 0603 | 3 | 0 | Generic R/0R/0603
R302 | 0603 | 1 | 330 | Generic R/330/0603
R303 | 0603 | 1 | 13k | Generic R/13k/0603
R304 | 0603 | 1 | 7k5 | Generic R/7k5/0603
R307, R503, R504 | 0603 | 3 | 3k3 | Generic R/3k3/0603
R314 | 0603 | 1 | 2k | Generic R/2k/0603
R315 | 0603 | 1 | 150k | Generic R/150k/0603
R316 | 0603 | 1 | 4k3 | Generic R/4k3/0603
R320 | 0603 | 1 | 430 | Generic R/430/0603
R401, R402 | 0603 | 2 | 5k1 | Generic R/5k1/0603
R407, R408 | 0603 | 2 | 22 | Generic R/22R/0603
R409, R410 | 1210 | 2 | 100 | Generic R/0R/0603
R501, R507 | 0603 | 2 | 3k9 | Generic R/3k9/0603
R502, R505 | 0603 | 2 | 39k | Generic R/39k/0603
RV301 | Potentiometer_Alps_RK097_Single_Horizontal | 1 | 10k | C470577
SW201, SW203, SW204, SW205, SW206, SW207, SW208 | SW_SPST_PTS645 | 7 | Tactile switch | C221869
SW202 | SW_SPST_436351045816 | 1 | Tactile switch | C79174
U201 | LQFP-64_10x10mm_P0.5mm | 1 | STM32F405RGTx | C15742
U202 | SOT-23-5 | 1 | TPS7A2033 | C2862740
U203 | SOT-23-6 | 1 | TP6841S6 | C2844924
U301, U503, U504 | SOIC-8_3.9x4.9mm_P1.27mm | 3 | MCP6002 | C116706
U302 | DFN-14-1EP_3x3mm_P0.4mm_EP1.78x2.35mm | 1 | MAX9814 | C41714
U401 | SOT-23-6 | 1 | USBLC6-2SC6 | C7519
U501, U502 | MSOP-8_3x3mm_P0.65mm | 2 | MCP4551-103 | C636116
Y201 | Crystal_SMD_3225-4Pin_3.2x2.5mm | 1 | 8 MHz | C2442665

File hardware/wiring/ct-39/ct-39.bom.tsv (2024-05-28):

Id | Description | Qty | Unit | Designators | P/N | Manufacturer
1 | Cable, 6 x 24 AWG | 1 | m | Yaesu CT-39 | CT-39 | Yaesu
2 | Connector, 6-pin Mini-DIN, male, 6 pins | 1 |  | Mini-DIN 6
3 | Connector, D-Sub, male, 9 pins | 1 |  | DE-9

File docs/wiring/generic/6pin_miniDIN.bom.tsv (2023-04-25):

Id | Description | Qty | Unit | Designators | P/N | Manufacturer
1 | Cable, 6 x 24 AWG | 1 | m | Belden 9536 | 9536 | Belden
2 | Connector, 6-pin miniDIN, male, 6 pins | 1 |  | miniDIN-6
3 | Connector, D-Sub, male, 9 pins | 1 |  | DE-9

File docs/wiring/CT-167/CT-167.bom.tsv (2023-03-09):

Id | Description | Qty | Unit | Designators | P/N | Manufacturer
1 | Cable, Cable CT-167 (pigtail), 10 x 24 AWG | 1 | m | CT-167 | CT-167 | Yaesu
2 | Connector, 10-pin miniDIN, male, 10 pins | 1 |  | mini-DIN-10
3 | Connector, D-Sub, male, 9 pins | 1 |  | DE-9

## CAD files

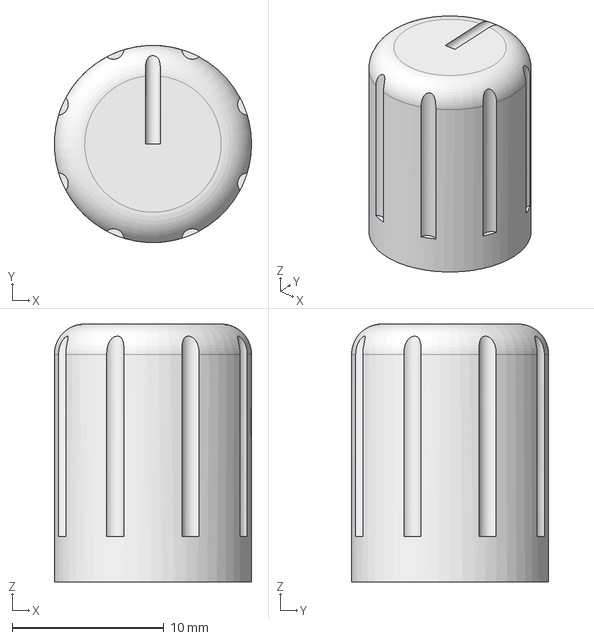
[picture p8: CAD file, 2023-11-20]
case/knob/knob2.step
13.0 x 13.0 x 17.0 mm

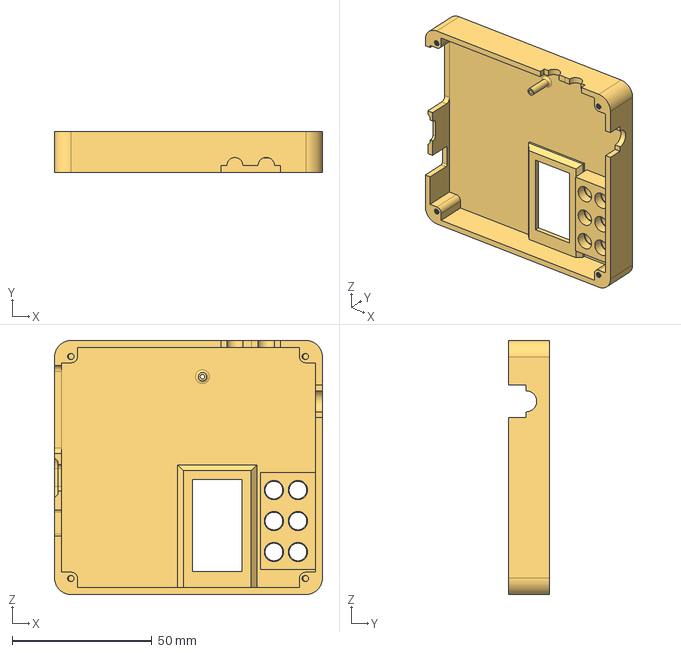
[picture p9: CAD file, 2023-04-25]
case/revision_01d/Step/Mod17_Top_Cover_With_Graphics.step
96.0 x 14.8 x 91.0 mm

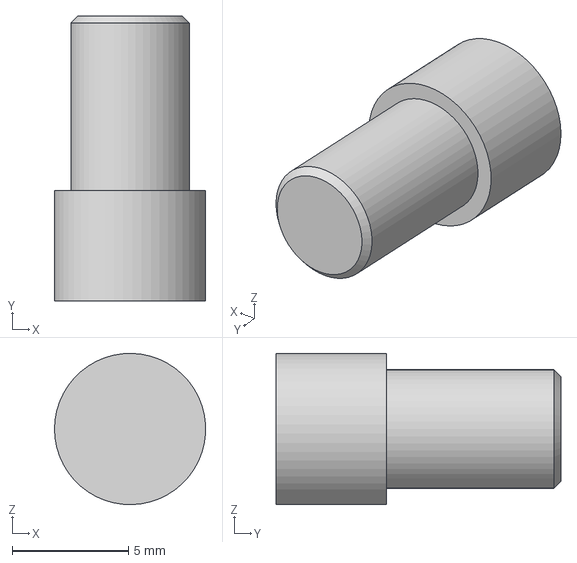
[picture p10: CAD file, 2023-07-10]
case/revision_01e/Step/Mod17_PwrButton.step
6.49 x 12.2 x 6.50 mm

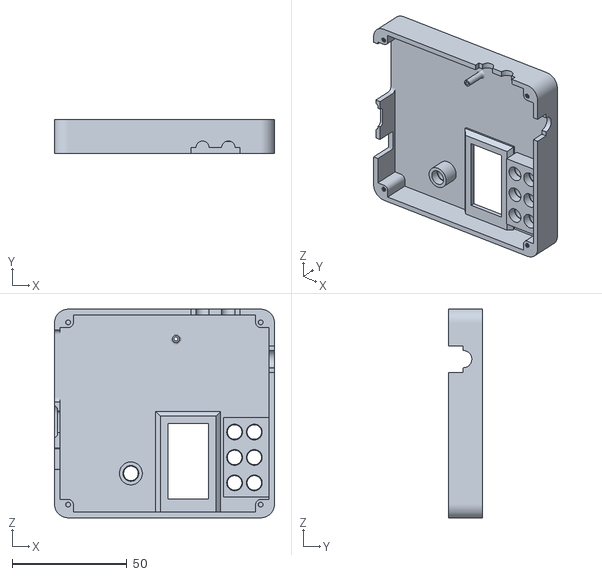
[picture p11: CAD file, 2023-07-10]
case/revision_01e/STL/Mod17_Top_Cover_RevE_With_graphics.stl
96.0 x 14.8 x 91.1

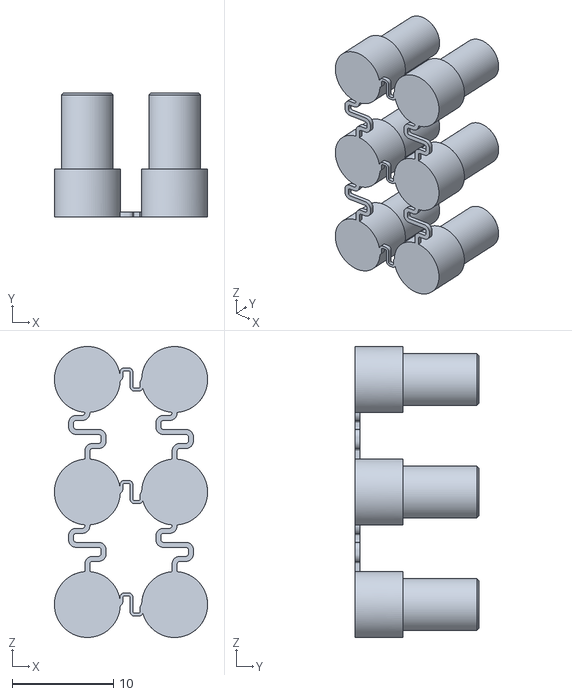
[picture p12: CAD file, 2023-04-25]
case/revision_01e/STL/Buttons.stl
15.1 x 12.2 x 28.7

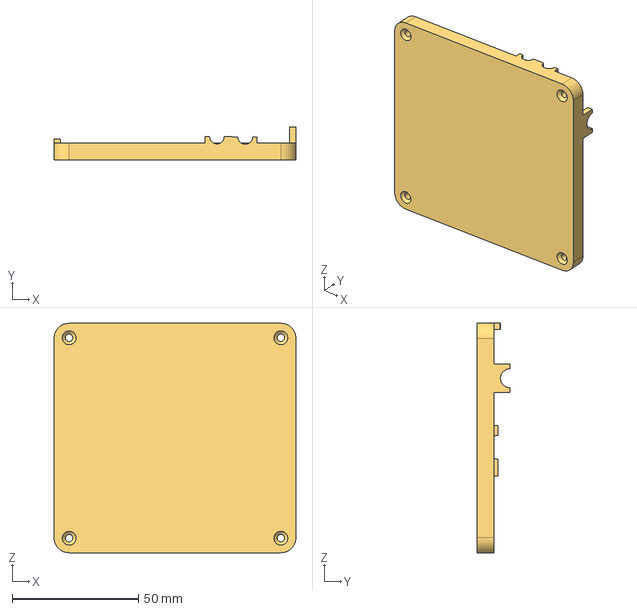
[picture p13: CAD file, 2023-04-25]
case/revision_01e/Step/Mod17_Bottom_Cover.step
96.0 x 13.1 x 91.0 mm

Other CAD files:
case/revision_01d/STL/Top_Cover_With_graphics.stl
case/revision_01d/Step/Mod17_Top_Cover_Without_Graphics.step
case/revision_01e/Step/Mod17_revE_Top_Cover_With_Graphics.step
case/revision_01e/Step/Mod17_Buttons.step
case/knob/knob2.FCStd
case/knob/knob2.stl
case/revision_01d/STL/Mod17_Top_Cover_Without_graphics.stl
case/revision_01e/STL/Mod17_Bottom_Cover.stl
case/revision_01e/STL/Mod17_PwrButton.stl

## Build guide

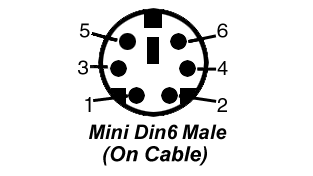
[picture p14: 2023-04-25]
docs/wiring/generic/minidin6.png

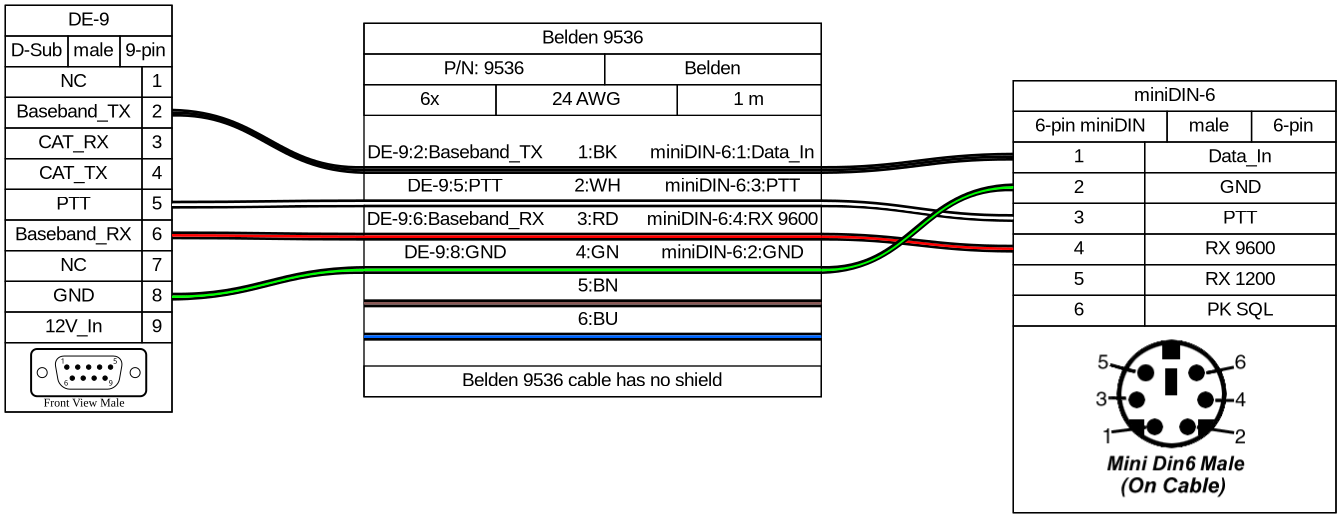
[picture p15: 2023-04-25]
docs/wiring/generic/6pin_miniDIN.png

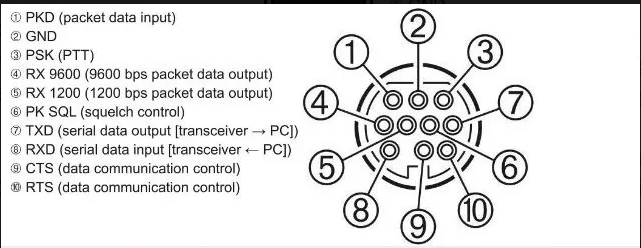
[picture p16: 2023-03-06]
docs/wiring/CT-167/minidin10.png

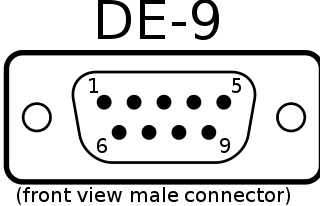
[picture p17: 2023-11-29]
hardware/wiring/ct-39/dsub9.png

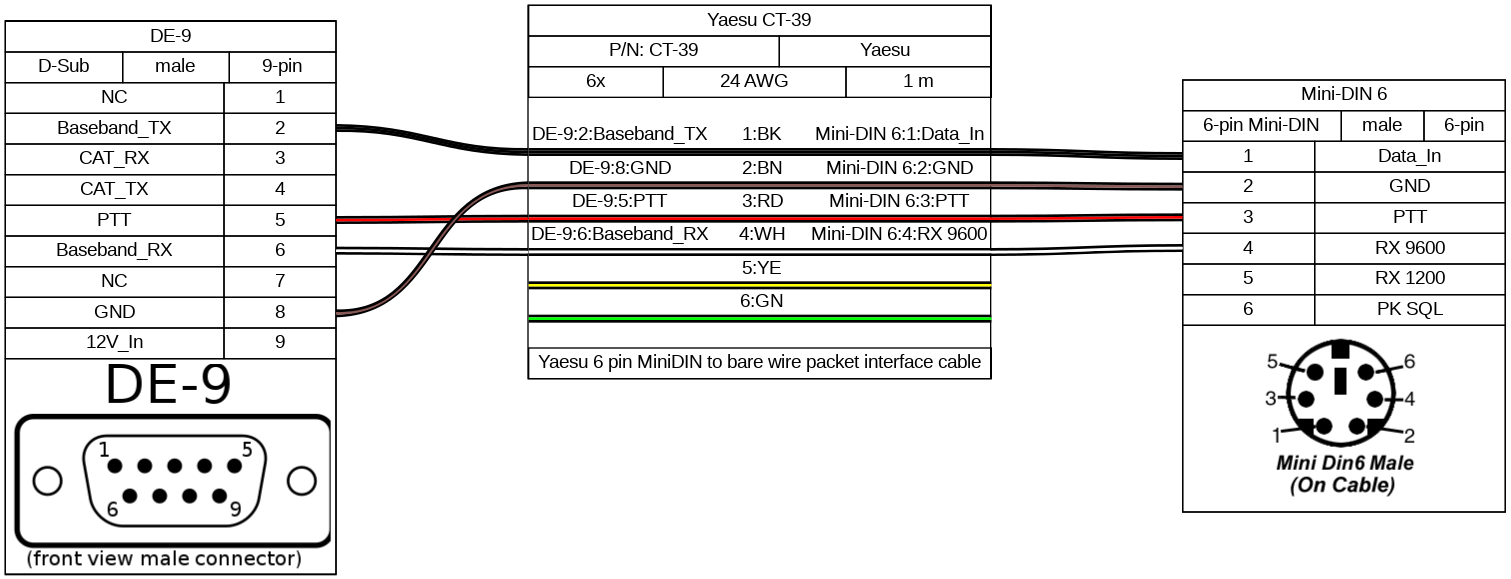
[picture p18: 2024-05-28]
hardware/wiring/ct-39/ct-39.png

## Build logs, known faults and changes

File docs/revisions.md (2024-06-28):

## Revisions

### Revision 0.1a

This is the initial prototyping revision and not yet designed with "ease of use and enclosing" in mind. Its main purpose is getting OpenRTX up and running on the hardware and providing a proof of concept.

#### Errata of Revision 0.1a
* Do not install R23 (1k5 pull-up on USB D+) as the STM32F4 has an integrated pull-up
* Replace C3 and C6 with 18pF, otherwise Y1 starts too slow during USB DFU
* Short BOOT0 on pin 94 to PB8 on pin 95 to be able to use SW4 in software
* The 2.5mm mono jack used for the Kenwood 2-pin speaker mic has the "sleeve" connection where stereo plugs have the "ring". This means that the speaker mic has no GND connection. To fix this, add a bodge wire to the outer shell of the mono jack to GND. Next revisions will use a stereo jack with shorted ring and sleeve connections.

### Revision 0.1b
Fixed some bugs:
* Changed audio amp from LM386 to LM4861MX
* Mic amplifier changed from LMV341 to MAX9814 (with an AGC)
* Fixed Kenwood connector
* Fixed baseband processing at U6/U7
* C3/C6 value change from 22 to 18p
* Changed micro from STM32F407VETx to -405RGTx
* Added TPS5431 DC/DC converter IC
* Added MAX3232 and `CAT_TX`/`CAT_RX` at DE9 connector

### Revision 0.1c

* Reduced audio amplifier gain (R3 value change 510k->22k)
* Fixed `RADIO_RX` baseband DC bias

### Revision 0.1d

* Changed supply voltage for U6 and U7 (baseband filter Op-Amps) to 5V and replaced MCP602 with MCP6002 as the former ICs are not rail2rail capable on their input
* Fixed `CAT_TX` and `CAT_RX` solder jumpers
* Fixed volume knob direction
* Replaced PSU with in-stock parts
* Replaced MAX3232 with simple 5V/3.3V level shifters as most, if not all, radios use either 5V or 3.3V TTL instead of RS232
* Replaced STM32F405RGT6 with GD32F405RGT6 - these ICs are pin and code compatible

### Revision 0.1e

* Replaced digital potentiometers with multiturn ones to improve parts availability
* Moved the TX potentiometer from the op-amp's output to between STM32 and the first op-amp
* Added power-on button
* Fixed misc BOM errors and removed a few unnecessary components from the schematic

#### Errata of Revision 0.1e

~~R31 has too high value. Add a 2.2k resistor across it (in parallel) to increase the sound volume coming from the speaker. Alternatively, replace R31 with a 1.8k or 2k resistor.~~ Resolved.

### Revision 1.0

* Completely redesigned the board, making a design compatible with Hammond enlosures.
* Added connector for HMI board containing buttons and OLED screen.
* Added back digital potentiometers, keeping the footprint for multiturn potentiometers.
* Replaced RC low-pass filter between MCU and speaker power amplifier with an active Sallen-Key (3rd order) topology.
* Added OHIS connector
* Added connector for RTC battery
* Added pull-down resistor on shutdown-line (fixes the board not powering down from OpenRTX menu)

### Future revisions

Discovered an issue? Some suggestions for the next revision? Get in touch with us.

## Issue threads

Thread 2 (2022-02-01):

C22 cap in rev. 0.1c

sp5wwp, 2022-02-01:
C22 should be removed or replaced with a short.

mathisschmieder, 2022-03-28:
Do you have a reason for this? We can play around with a 0R resistor instead of C22, but I'll leave the footprint in for now.

sp5wwp, 2022-03-28:
Timer doesn't work with that cap in place. Ok, 0R works for me.

mathisschmieder, 2022-03-28:
Ok! "Fixed" in 0.1d

Closed 2022-03-28.

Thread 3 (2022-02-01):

IC1 "Shutdown" pin

sp5wwp, 2022-02-01:
`Pin 1 should be connected to VDD to disable the amplifier or to GND to enable the amplifier. This pin should not be
left floating.` In our case this pin can be set either to GND or 3.3V, while the amplifier is supplied with 5V. We should add a pull-up to 5V line and drive an IRLML2060 from the micro, much like we do for the PTT_OUT line.

mathisschmieder, 2022-03-28:
It's working perfectly fine with 3.3V, I won't change this for now.

Closed 2022-03-28.

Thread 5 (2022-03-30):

Change OpAmp supply to 5V

mathisschmieder, 2022-03-30:
MCP602 (and others, probably) limit the common mode *input* voltage to Vsupply - 1.2V. We need clippy-free operation up to 3.3V to utilize all them bits, so we should supply the OpAmps with 5V.

sp5wwp, 2022-09-30:
Can this be closed?

mathisschmieder, 2023-05-02:
VAA was tied to 5V in 0.1d+

Closed 2023-05-02.

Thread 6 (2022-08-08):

Part numbers missing

sp5wwp, 2022-08-08:
BOM lacks the PNs of the OLED display and the RV1 pot.
@mathisschmieder

sp5wwp, 2022-10-25:
`RV1`s value can be in 10..100k range. Just make sure its logarithmic (for audio purposes).

Example part number: `PTR901-2025F-A103` (Bourns).

sp5wwp, 2022-11-29:
`MCP4551T-503E/MF` can be used for both `U8` and `U9`, with `R42` value changed to 10k.

sp5wwp, 2023-05-17:
Fixed.

Closed 2023-05-17.

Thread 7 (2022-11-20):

Digital potentiometer out of stock everywhere

ManoDaSilva, 2022-11-20:
Hi!

Amazing work you've been doing on developing this modem to get as many people as possible going with M17! I'm preparing an order with JLCPCB, with assembled components, etc.  I'm now looking for the digital potentiometers, however it's out of stock everywhere. Is there a suitable replacement I can look for? Or is there a way to replace it with a physical potentiometer to manually adjust the filters? How does openRTX interact with those?

Thanks for the help!

Manoel - ON6RF

silseva, 2022-11-20:
Hi!
Digital potentiometers are used to regulate the level of the audio signal to and from the radio. You can replace those with physical ones without problems.

73,
Silvano IU2KWO

sp5wwp, 2022-11-29:
My proposal is to use 50k ones for both `U8` and `U9`. 50k ones are available at Mouser. And change the `R42` to 10k.

sp5wwp, 2023-05-16:
Done.

Closed 2023-05-16.

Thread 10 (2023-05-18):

Wrong PNs in BOM

sp5wwp, 2023-05-18:
Replace part numbers for `Q2`, `Q3` and `SW3` and regenerate the BOM.

mathisschmieder, 2023-05-19:
Fixed in 6e07c9b07ef84609fef333dac708ae9ae7ddf7ba

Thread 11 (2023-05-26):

Low decoded audio volume in rev 0.1e

sp5wwp, 2023-05-26:
After changing the value of the volume potentiometer from 50k to 10k, the signal at the audio amplifier's input decreased in amplitude.

Workaround: solder a 2k resistor across R31 (22k) to increase amplifier's gain.

sp5wwp, 2023-06-15:
Fixed.

kc1awv, 2023-07-01:
updated BOM to include changes in commit a85bac8

hofmand, 2024-11-04:
> Workaround: solder a 2k resistor across R31 (22k) to increase amplifier's gain.

Could we get instructions for this workaround? The board I just received from Lilygo has low audio output and I don't even know where to find R31.

sp5wwp, 2024-11-04:
I believe it's this one, should have `223` written on it.
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

hofmand, 2024-11-05:
Thanks, the one on my board has "182" which seems correct.

Closed 2023-06-15.

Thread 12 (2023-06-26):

Wrong values for R53/R54

sp5wwp, 2023-06-26:
In 0.1e, `R53` should be 0 ohm and `R54` left unpopulated.

kc1awv, 2023-07-01:
Resolved in commit 9b9289c

Closed 2023-07-01.

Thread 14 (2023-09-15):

Shutdown issue

sp5wwp, 2023-09-15:
Due to leakage current reaching one of the transistors i nthe power control section, the `Shutdown` menu entry doesn't work as intended.

Workaround: solder a 10k resistor between STM32's pin 50 or D7's pin 1 (`GPIO_POWER` net) and ground.

sp5wwp, 2023-11-16:
Will be fixed in revision 1.0.

Closed 2023-11-16.

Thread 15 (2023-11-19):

License update

mdiepart, 2023-11-19:
We have been discussing a license change for this project. Mainly, we want to change from the TAPR Open Source Hardware License to the CC-BY-NC-SA license (version 4).

For now, the following contributors expressed their agreement with this change:
@sp5wwp
@kc1awv
@mathisschmieder
@tarxvftech

We also have identified the following contributors but haven't asked your opinion yet:
@AC4AG (under the usernames AC4AG and popracer) that contributed to the 3D printed cases for revs 0.1d and 0.1e.
@abfparts that also contributed to the 3D printed cases
@n1zzo that contributed to the drawio diagram.

Can I please ask everybody, to confirm if they agree about this license change? And more especially, could those who we haven't asked about this yet please tell us if they agree or not?

mdiepart, 2023-11-19:
To be more accurate, we want to change the license of the repository for the revision 1 mainly. But everything in the repository will be under that license once the change is done. The previous revisions will still be under TAPR OSHL.

tarxvftech, 2023-11-19:
I agree. I don't think I actually have copyrightable contributions but I appreciate the attention to detail in this license change.

mdiepart, 2023-12-06:
It have finally been decided to let go of the NC clause mostly because we believe the manufacturers that want to manufacture the board will do it irrespective of the license we choose. NC clause is also refused by OSHW for their certification.
It was decided with @sp5wwp, @kc1awv and @mathisschmieder to opt for a CERN-OHL-V2-W (https://ohwr.org/cern_ohl_w_v2.txt).

Can I please ask you guys (@AC4AG, @abfparts and @n1zzo) to say here if you agree or disagree with this proposed change?
Please not that we do not ask you to bother you. You have contributed to this repository so we NEED your agreement to re-license your contributions.

If we have not received any answers by 10/12/2023 those changes will be moved to another repository.

mdiepart, 2023-12-08:
Amazing, thank you very much!

n1zzo, 2023-12-08:
I agree about the license change!

tarxvftech, 2023-12-09:
I agree. Furthermore if there _is_ anything in here that's actually mine, I assign copyright and ownership of everything of mine in this repo up to now to Steve KC1AWV.

mdiepart, 2023-12-09:
Thank you all for your replies, it is much appreciated!

Closed 2023-12-09.

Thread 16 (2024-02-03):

Add some more clearance around mounting holes

dd5xl, 2024-02-03:
Clearance around 3 of 4 mounting holes is not sufficient to add washers or to use a wrench to tighten the nuts.

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

In case of a PCB redesign please consider to add some more clearance.

sp5wwp, 2024-06-09:
1.0 is a complete redesign, so it should be OK then :)

mdiepart, 2024-07-28:
Revision 1.0 has at least 1.8mm of clearance between the edge of the hole and the closest component. This clearance can be increased if opting for digital potentiometers instead of the multiturn potentiometers. Revision1.0 is also designed with a specific enclosure in mind.

Closed 2024-07-28.

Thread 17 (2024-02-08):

Pinout of DB-9 can be wrong

pe1msz, 2024-02-08:
I noticed that a board I got in, has a female connector mounted, which causes some pin-numbers to be wrong.

I use a GM950 Motorola, and that seems to work great sofar (it has a data transmit and a flat audio out).

I am just wondering what the best RX-Post value is on the M17-module (allignable with a multiturn pot)

sp5wwp, 2024-06-09:
Which pins are wrong?

For the calibration procedure, see [this](https://github.com/OpenRTX/OpenRTX/issues/184).

pe1msz, 2024-06-11:
Pinnumbering on the DB9 was not the same as on the connector.

I will get more details for you.

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

mdiepart, 2024-07-28:
Is this issue solved?

kc1awv, 2024-08-05:
> I noticed that a board I got in, has a female connector mounted, which causes some pin-numbers to be wrong.

The pin numbers are always going to be the same, regardless of the connector's gender. If you're referring to the wiring diagrams provided in the repo, remember that the diagrams describe the _cable_, and not the radio it's plugging into.

pe1msz, 2024-08-06:
You are right, the pins are correct! I looked at the pinout of the connector which is in the doc-folder, and that shows the front of a male connector. The board has a female connector, so i believe it would be useful to show the female connector. In my case I had the idea that the board had the wrong connector, thus having a wrong pinout.

pe1msz, 2024-08-12:
I agree, but if you use the numbers on the picture, they are reversed as it is not the back but the front of the connector (male)

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

sp5wwp, 2024-08-31:
It says "male" in the image. Closing.

Closed 2024-08-31.

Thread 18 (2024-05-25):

Short circuit VDD to Ground

DL6YA, 2024-05-25:
I uploaded the files for version r0.1e to JLCPCB the way it was described. All 10 boards have a short circuit fromm VDD to Ground. JLCPCB told me that the file for the NPTH holes should not be on the copper layer? Did someone had similar problems? Now I am afraid burning another 300$ for useless boards.
![Uploading 001 (2).png…]()

sp5wwp, 2024-06-09:
We are very sorry to hear this. We have ordered multiple boards without facing any issues. Your image did not upload, can you try again? We need more detailed info.

DL6YA, 2024-07-11:
Hey, it was just a production mistae. Got a new production and they work so far. Still didnt manage to make a qso, but our group is working on the cbale for there radios. hopfully we will report good news soon. are there any information about the adjustment for Rx an Tx?

mdiepart, 2024-07-28:
Given that this was a production mishap and that the current revision is now revision 1.0, I'm gonna close this issue.

Feel free to re-open if this happens on the new revision too :)

Closed 2024-07-28.

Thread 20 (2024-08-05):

M17 Rev 1.0

toshi-cxh, 2024-08-05:
Module 17 Revision 1.0

I was able to assemble the Main PCB and HMI PCB into the case, but the switches on the HMI board do not work properly.
Down button -- works as Enter
Right button -- works as Up
Enter button -- works as Escape
Only 3 switches respond, and the other switches, including Power, do not respond.

I assembled a second set, but the situation was the same as the first set.
The firmware written to the main board is: v0.3.7-1-g031ecda1d

Since it is not possible to write a callsign, I removed the HMI board, attached the OLED 1.3 inch module used on the previous board (Rev 0.1d/e) to the main board, and was able to set the callsign. .
The main board only seems working properly.

toshi-cxh, 2024-08-10:
The problem is still not resolved.
After removing the device printed with "3619" mounted on U4 at JLCPCB and installing "CAP1206-1-SL" purchased from MOUSER, the 6 switches except POWER started working properly. Power is supplied from USB C.
However, when I apply 12V to the DC input and press the POWER switch, the board will not start.

toshi-cxh, 2024-08-20:
The 3.3V regulator I ordered arrived today.  I installed it on U2, the Power switch started working properly. At the same time, the second unit was also housed in a new case (blue). When putting it in the case, I replaced the cable between the main and HMI board with a 6cm shorter cable.
Now, the assembly is finally complete.

Closed 2024-08-21.

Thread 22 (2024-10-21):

Module17_Rev_1.0.zip appears to be broken

kandev, 2024-10-21:
I have just tried to follow the PCB ordering guide, but the gerber files zip archive is broken and can't be opened.

kandev, 2024-10-21:
Actually all the zip files are broken!? Are they zip files at all?

mdiepart, 2024-10-21:
Hello,

I just tried opening those files and it works without any issue. I know several people did so too without any issue either.

We will need more details on the problems you are having but it probably does not come from the gerber archives.

sp5wwp, 2024-10-21:
Opens with 7z with no problems (under Windows 10).

kandev, 2024-10-21:
Tried on both Windows (integrated zip, winrar and 7zip) and in Linux with unzip - same result always:

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

mdiepart, 2024-10-21:
Are you sure you did not download the html page as an archive?

sp5wwp, 2024-10-21:
It is an HTML page...

mdiepart, 2024-10-21:
The link you need to use to download the archive via wget is this one: https://github.com/M17-Project/Module_17/raw/refs/heads/main/hardware/mainboard/production/Module17_Rev_1.0.zip

Closing as it is a non-issue.

kandev, 2024-10-21:
Yup, that was it. The direct links to the files in the manual are not so direct :)
Thank you!

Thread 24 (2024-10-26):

DE-9 connector pinout

sp5wwp, 2024-10-26:
Why it isn't shown in the readme anymore?

ben-kuhn, 2025-10-06:
Came here looking for this as well as I need to build a cable for a different transceiver.

ben-kuhn, 2025-10-06:
https://github.com/M17-Project/Module_17/pull/25

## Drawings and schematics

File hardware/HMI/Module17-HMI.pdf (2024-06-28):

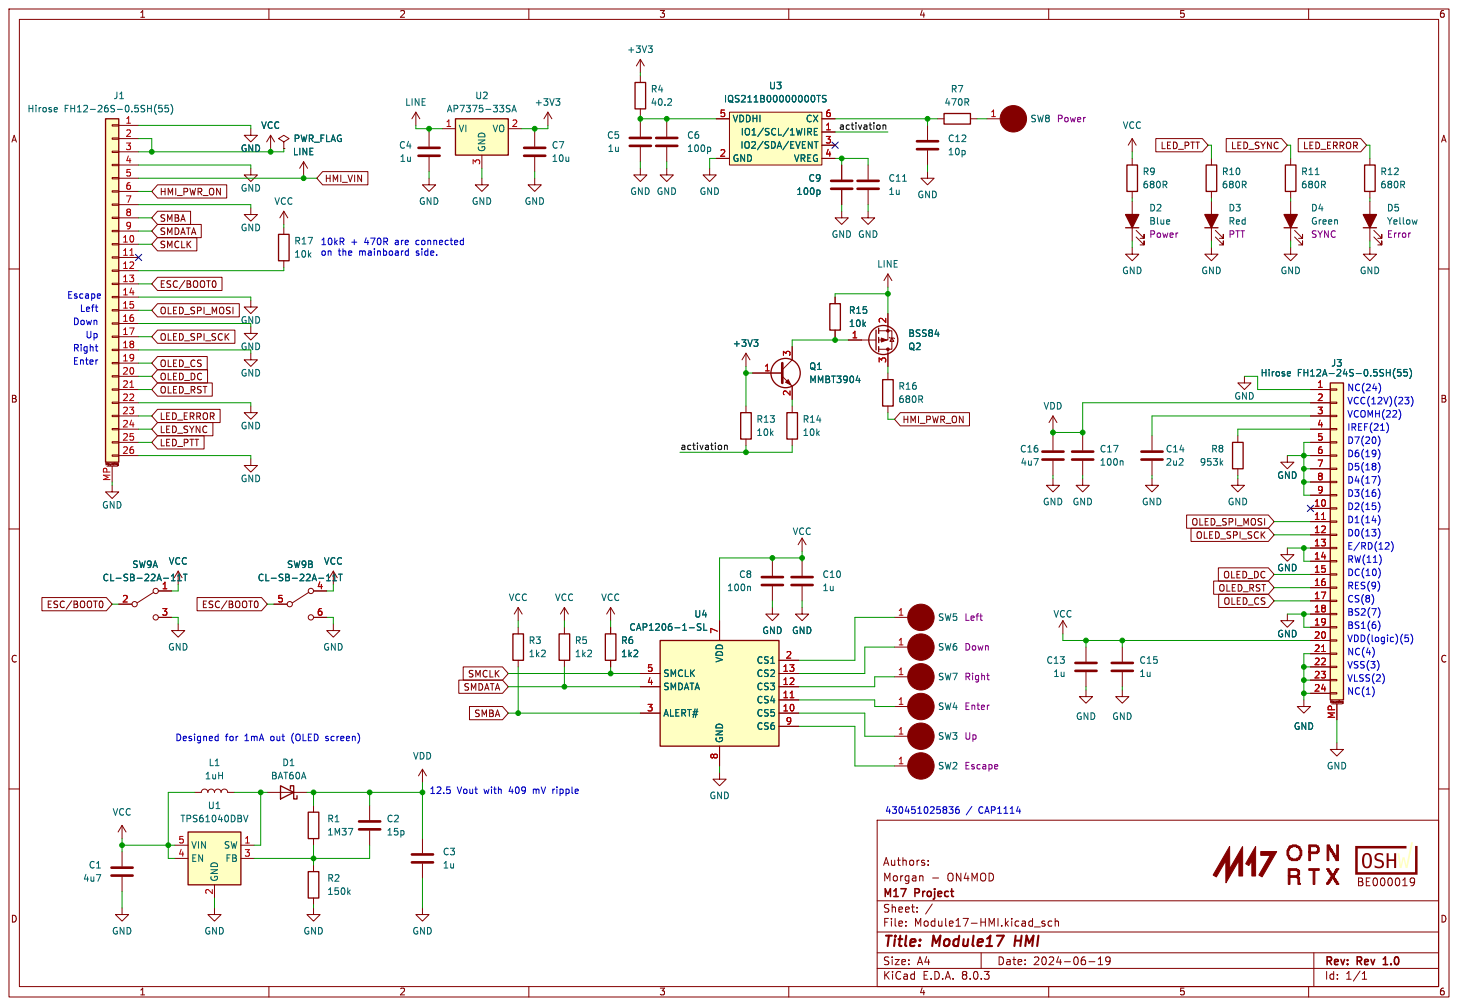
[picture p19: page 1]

Designed for 1mA out (OLED screen)

2 FB 3 EN 4 VIN 5 U1 TPS61040DBV VCC GND

12.5 Vout with 409 mV ripple

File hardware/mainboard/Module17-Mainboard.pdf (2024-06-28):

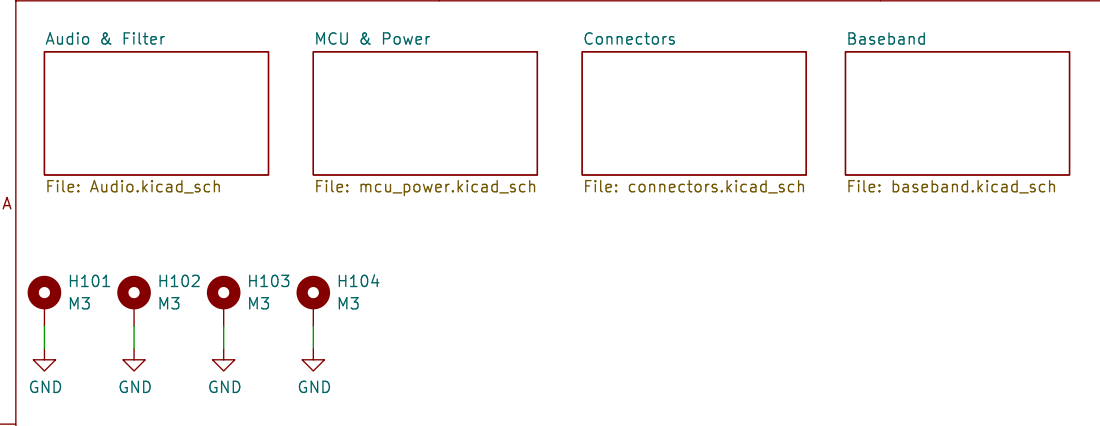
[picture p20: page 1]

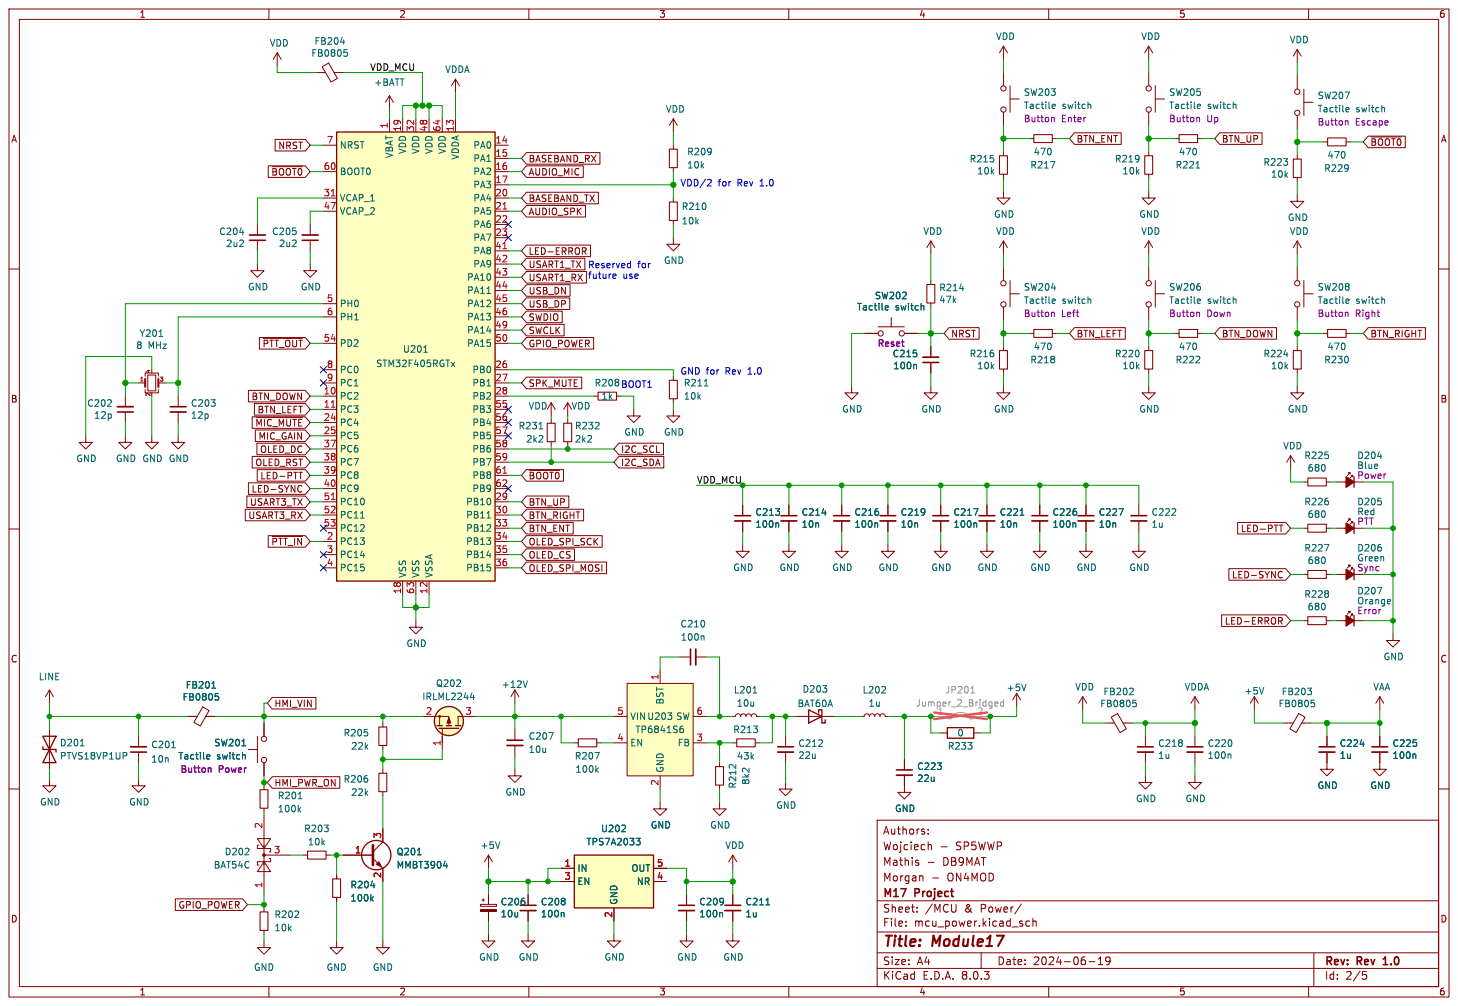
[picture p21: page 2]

1 PC2 10 PC3 11 VSSA 12 VDDA 13 PA0 14 PA1 15 PA2 16 PA3 17 VSS 18 VDD 19 PC13 2 PA4 20 PA5 21 PA6 22 PA7 23 PC4 24 PC5 25 PB0 26 PB1 27 PB2 28 PB10 29 PC14 3 PB11 30 VCAP_1 31 VDD 32 PB12 33 PB13 34 PB14 35 PB15 36 PC6 37 PC7 38 PC8 39 PC15 4 PC9 40 PA8 41 PA9 42 PA10 43 PA11 44 PA12 45 PA13 46 VCAP_2 47 VDD 48 PA14 49 PH0 5 PA15 50 PC10 51 PC11 52 PC12 53 PD2 54 PB3 55 PB4 56 PB5 57 PB6 58 PB7 59 PH1 6 BOOT0 60 PB8 61 PB9 62 VSS 63 VDD 64 NRST 7 PC0 8 PC1 9 U201 STM32F405RGTx VDD VDD

VDD_MCU
SW205 Tactile switch Button Up R206

SW207 Tactile switch Button Escape R207

470 SW203 Tactile switch Button Enter R217

VDD/2 for Rev 1.0 BOOT1 Reserved for

SW206 Tactile switch Button Down GND
VDD

470 SW208 Tactile switch Button Right +5V R233

SW202 Tactile switch Reset GND GND

D205 Red PTT D204 Blue Power C215

2 FB 3 EN 4 VIN 5 SW 6 U203 TP6841S6

2 3 Q201 MMBT3904 SW201 Tactile switch Button Power GND

2 EN 3 NR 4 OUT 5 U202 TPS7A2033 GND GND

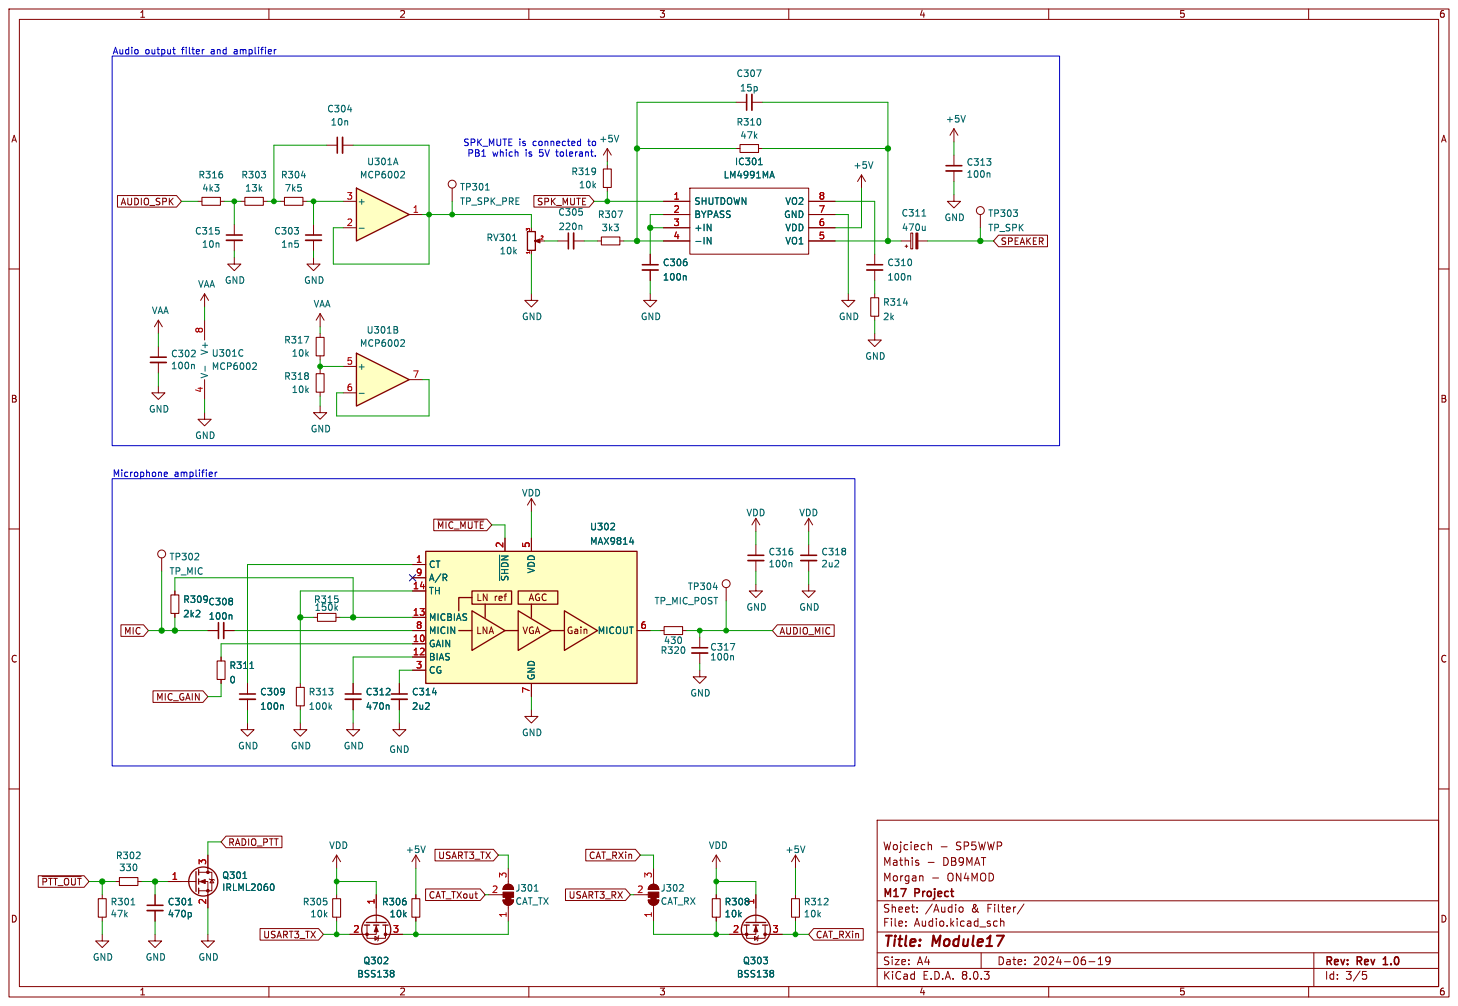
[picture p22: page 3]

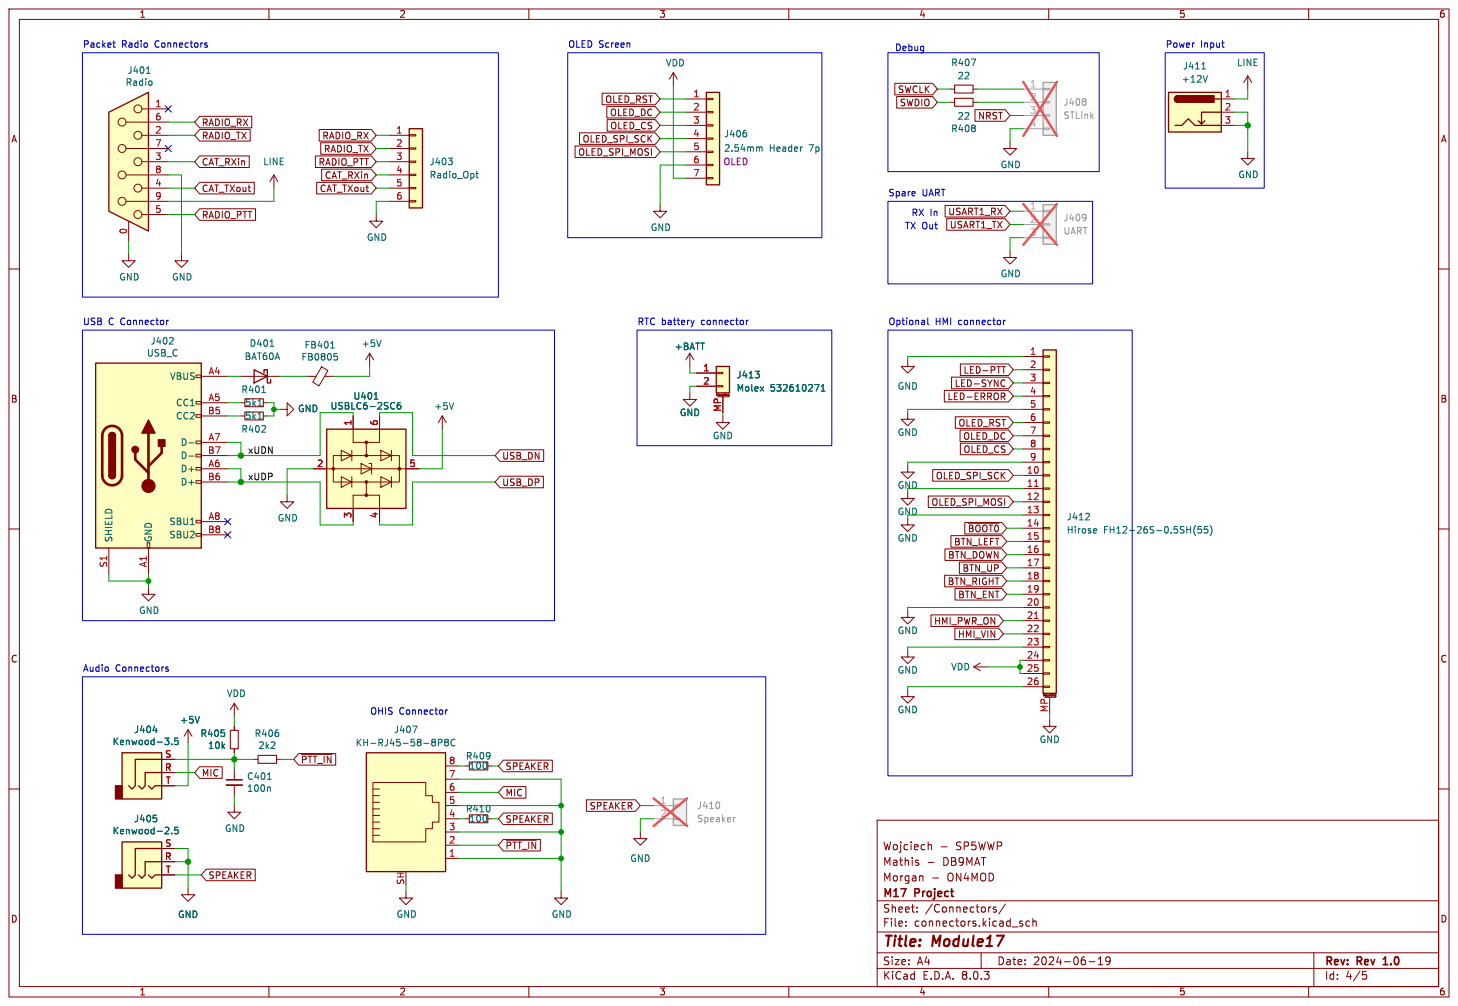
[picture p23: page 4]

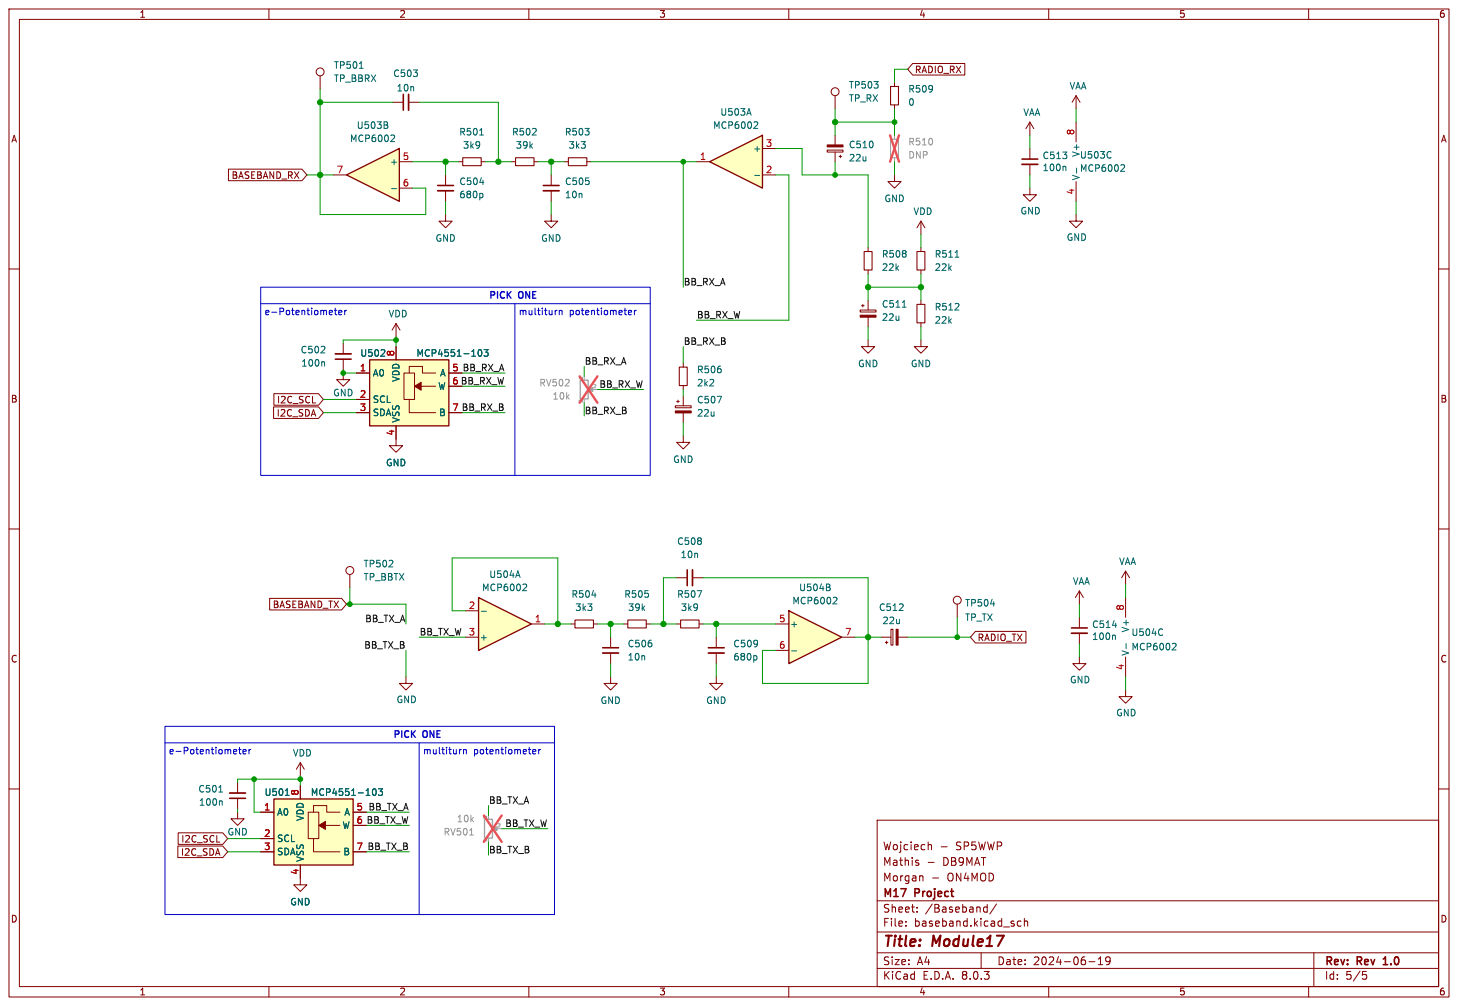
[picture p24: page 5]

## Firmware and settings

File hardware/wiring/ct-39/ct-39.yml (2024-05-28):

connectors:
  DE-9:
    type: D-Sub
    image: 
      src: dsub9.png
    subtype: male
    pinlabels: [NC, Baseband_TX, CAT_RX, CAT_TX, PTT, Baseband_RX, NC, GND, 12V_In]
  Mini-DIN 6:
    type: 6-pin Mini-DIN
    image:
      src: minidin6.png
    subtype: male
    pinlabels: [Data_In, GND, PTT, RX 9600, RX 1200, PK SQL]

cables:
  Yaesu CT-39:
    gauge: 24 AWG
    length: 1
    colors: [BK, BN, RD, WH, YE, GN]
    wirecount: 6
    shield: false
    notes: "Yaesu 6 pin MiniDIN to bare wire packet interface cable"
    pn: "CT-39"
    manufacturer: "Yaesu"

connections:
  -
    - DE-9: [2,5,6,8]
    - Yaesu CT-39: [1,3,4,2]
    - Mini-DIN 6: [1,3,4,2]

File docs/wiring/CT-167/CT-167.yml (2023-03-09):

connectors:
  DE-9:
    type: D-Sub
    image: 
      src: dsub9.svg
    subtype: male
    pinlabels: [NC, Baseband_TX, CAT_RX, CAT_TX, PTT, Baseband_RX, NC, GND, 12V_In]
  mini-DIN-10:
    type: 10-pin miniDIN
    image:
      src: minidin10.png
    subtype: male
    pinlabels: [PKD, GND, PSK, RX 9600, RX 1200, PK SQL, TXD, RXD, CTS, RTS]

cables:
  CT-167:
    gauge: 24 AWG
    length: 1
    colors: [BN, BK, RD, OG, YE, GN, BU, GY, WH, BK]
    wirecount: 10
    shield: false
    notes: "NOTE: The CT-167 cable uses the thick black wire for GND"
    type: "Cable CT-167 (pigtail)"
    pn: "CT-167"
    manufacturer: "Yaesu"

connections:
  -
    - DE-9: [2,3,4,5,6,8]
    - CT-167: [1,7,8,3,4,2]
    - mini-DIN-10: [1,7,8,3,4,2]

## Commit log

2021-08-30 Initial commit of Module 17 / M17 SmartMic.
    [Audio.sch, Baseband.sch, M17-SmartMic.kicad_pcb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]
2021-08-30 Moved DAC signals to DAC channels (PA4/5)
    [Baseband.sch, Microcontroller.sch]
2021-08-30 Simplified values of R32 and C46,47
    [Audio.sch, Microcontroller.sch]
2021-08-31 Small fixes / updates
    * Fixed library path
    * Added 12 MHz TCXO
    * Replaced rotary encoder with more buttons
    * Changed radio connector pinout to be compatible with Repeater Builder and BI7JTA modem boards
    [Audio.sch, Microcontroller.sch]
2021-08-31 Replaced Xtal parallel R with series R
    [Audio.sch, Microcontroller.sch]
2021-08-31 Flipped C35
    [Audio.sch]
2021-09-07 Revision 0.1a ready for review
    [Audio.kicad_sch, M17-SmartMic.kicad_pcb, M17-SmartMic.kicad_sch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]
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2021-10-16 Added RTC and Test Points to r0.1b
    This marks production for revision 0.1b
    [Audio.kicad_sch, M17-SmartMic.kicad_pcb, M17-SmartMic.kicad_sch]
2021-11-21 Revision 0.1c
    Reworked PSU section and removed oopsies. Full changelog to come
    [Audio.kicad_sch, Audio.sch, BOM-M17-SmartMic.csv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]
2022-05-08 r0.1d
    The supply chain revision
    [Audio.kicad_sch, Audio.sch, BOM-M17-SmartMic.csv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]
2022-05-09 Update r0.1d
    Added speaker connector, beautified silk screen
    [Audio.kicad_sch, BOM-M17-SmartMic.csv, M17-SmartMic.kicad_pcb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]
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2022-11-07 Update part_assignments.csv
    updated D6,D8,D9 to C520634
    [part_assignments.csv]
2022-11-07 Update BOM-M17-SmartMic.csv
    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
    [BOM-M17-SmartMic.csv]
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2023-03-06 add wiring diagram for Yaesu 10-pin
    [yaesu_10pin_miniDIN.bom.tsv]
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2023-04-10 delete case
    case commit was misattributed
    [Buttons.stl, Mod17_Bottom_Cover.step, Mod17_Bottom_Cover.stl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]
2023-04-10 add case file
    Add 3d printed case file for rev01d
    [Buttons.stl, Mod17_Bottom_Cover.step, Mod17_Bottom_Cover.stl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]
2023-04-11 add generic 6-pin miniDIN wiring
    [6pin_miniDIN.bom.tsv]
2023-04-25 WIP r0.1e: replace digipots with regular multiturn pots
    [Audio.kicad_sch, M17-SmartMic.kicad_pcb, M17-SmartMic.kicad_sch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]
2023-05-06 WIP r0.1e power switch
    👀
    [Audio.kicad_sch, M17-SmartMic.kicad_pcb, Microcontroller.kicad_sch]
2023-05-06 Updates to the latching power switch
    WIP r0.1e, schematics can be considered final
    [M17-SmartMic.kicad_pcb, Microcontroller.kicad_sch]
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2023-05-16 Finished MPN for r0.1e
    Targeted towards LCSC/JLCPCB
    [Audio.kicad_sch, Microcontroller.kicad_sch]
2023-05-16 r0.1e PCBA files
    specifically for JLCPCB
    [Audio.kicad_sch, M17-SmartMic.kicad_pcb, Microcontroller.kicad_sch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]
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2023-05-17 Updated r0.1e production files
    J3 and J11 were missing previously
    [M17-SmartMic.kicad_pcb, Microcontroller.kicad_sch, bom.csv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]
2023-05-19 Updated JLC fabrication files
    Replaced reset button and BSS138 FETs
    [Audio.kicad_sch, Microcontroller.kicad_sch, bom.csv]
2023-06-15 Changed R31 to 1k8
    [Audio.kicad_sch, bom.csv]
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2023-07-01 Fix R53 to 0R link for 3V3 pullup, update BOM for R31 and R53
    [Microcontroller.kicad_sch, bom.csv]
2023-07-01 Revert "Fix R53 to 0R link for 3V3 pullup, update BOM for R31 and R53"
    This reverts commit 9b9289c11e60193cf5a0cddd13b62c4145e0a591.
2023-07-01 Revert "Merge remote-tracking branch 'origin/main' into main"
    This reverts commit 2e86e4066111431c9dfb042395a1f17233de766b, reversing
    changes made to 3880e228021d6506ff5a6ac426a77f17ffdc8eb9.
    [Microcontroller.kicad_sch, bom.csv]
2023-07-01 Fix KC1AWV original fixes
    Fix schematic and PCB layout. Populate R53 with 0R and update BOM to include R31 change
    [M17-SmartMic.kicad_pcb, Microcontroller.kicad_sch, bom.csv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]
2023-07-01 actually include R31 change this time
    [bom.csv]
2023-07-02 update BOM with SP5WWP replacements
    Updated Q2, Q3 with LCSC C400505 and SW3 with LCSC C221895
    [bom.csv]
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2023-07-18 Relocated some documentation files
    [6pin_miniDIN.bom.tsv, CT-167.bom.tsv]
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2023-07-19 Moved kicad project files
    [Audio.kicad_sch, M17-SmartMic.kicad_pcb, M17-SmartMic.kicad_sch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]
2023-07-19 Updated schematic title block
    [Audio.kicad_sch, M17-SmartMic.kicad_sch, Microcontroller.kicad_sch]
2023-07-19 Updated M17 Logo
    Logo centered in library. Did not move on the board
    [M17-SmartMic.kicad_pcb]
2023-07-19 Deleted unused parts fields
    [Audio.kicad_sch]
2023-07-19 Updated some board parameters
    Added length measurements, added board characteristics in pcb file
    [M17-SmartMic.kicad_pcb]
2023-07-19 Updated revision on the PCB print
    [M17-SmartMic.kicad_pcb]
2023-07-19 Updated D8, D9 MPN to generic MPN
    [Microcontroller.kicad_sch]
2023-09-11 cleaned up component's fields in PCB
    [M17-SmartMic.kicad_pcb]
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2023-09-11 Added 10k pull-down
    Solves the no-self-shutdown issue
    [M17-SmartMic.kicad_pcb, Microcontroller.kicad_sch]
2023-09-11 Added OHIS connector to the schematic
    [Audio.kicad_sch]
2023-09-11 Set the revision detection pins to the correct voltages for Rev 1.0
    PA3 set to VDD/2. PB0 set to GND.
    [M17-SmartMic.kicad_pcb, Microcontroller.kicad_sch]
2023-09-18 Reworked audio output diagram
    [Audio.kicad_sch, M17-SmartMic.kicad_sch, Microcontroller.kicad_sch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]
2023-09-18 Placed both e-potentiometers and multiturn potentiometers on schematic
    [baseband.kicad_sch]
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2023-09-18 Modified components references
    Modified references to fit the previous references (from before adding the new sheets)
    [Audio.kicad_sch, baseband.kicad_sch, connectors.kicad_sch]
2023-09-18 Started new PCB layout
    [M17-SmartMic.kicad_pcb, baseband.kicad_sch]
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2023-09-21 Reworked schematic
    Rearranged disposition and renumbered components
    [Audio.kicad_sch, M17-SmartMic.kicad_pcb, M17-SmartMic.kicad_sch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]
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2023-12-09 PCB Layout [WIP] + HMI connector
    Added ZIF connector for HMI, updated reset button reference, added backup power connector for RTC + general layout progress
    [M17-SmartMic.kicad_pcb, connectors.kicad_sch, mcu_power.kicad_sch]
2023-12-09 Replaced pkl symbols with kicad library symbols
    [Audio.kicad_sch, M17-SmartMic.kicad_pcb, baseband.kicad_sch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]
2023-12-09 Replaced pkl footprints with kicad standard library footprints
    [Audio.kicad_sch, M17-SmartMic.kicad_pcb, baseband.kicad_sch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]
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2023-12-09 Configured manufacturing capabilities, fixed DRC errors
    [M17-SmartMic.kicad_pcb]
2023-12-09 Re-ordered audio connectors
    The OHIS connector and kenwood connectors have been swapped. Kenwood connector have also been flipped. This was made to avoid having the cable out of the kenwood connector collide with the shaft of the volume potentiometer.
    [M17-SmartMic.kicad_pcb]
2023-12-09 Fixed 3.5mm kenwood 3d model location
    [M17-SmartMic.kicad_pcb]
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2023-12-10 Updated OSHW logo
    Added OSHW logo to schematic, updated board logo
    [M17-SmartMic.kicad_pcb, M17-SmartMic.kicad_sch]
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2023-12-11 Updated various symbols attributes
    Updated various components (mostly LEDs and switches) to simplify the BOM and make it more easily readable.
    [Audio.kicad_sch, M17-SmartMic.kicad_pcb, connectors.kicad_sch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]
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2023-12-11 Removed USB serial resistors
    Those are not needed on STM32F405 series line
    [M17-SmartMic.kicad_pcb, connectors.kicad_sch]
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2024-01-03 Fixed baseband trimming potentiometers MPN
    [M17-SmartMic.kicad_pcb, baseband.kicad_sch]
2024-01-03 Updated HMI_PWR_ON and Net-(510-Pad2) layout
    moved trace to keep a gnd sliver around, placed a few vias
    [M17-SmartMic.kicad_pcb]
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2024-01-03 Made the board 0.5mm wider
    Effectively reverting commit ef7688b10c0facac2c1ed25a8adbc8398abe4afe.
    The 99.5mm board has a bit of play in the enclosure. Making it 100mm will make the fit snug.
    [M17-SmartMic.kicad_pcb]
2024-01-08 Made the board 0.5mm wider
    Fixed corners
    [M17-SmartMic.kicad_pcb]
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2024-01-09 Updated HMI
    Added JLCPCB placeholder for batch number, removed useless texts
    [Module17-HMI.kicad_sch, Module17-Side_Panels_Back.kicad_pcb, Module17-Side_Panels_Front.kicad_pcb]
2024-01-11 Updated HMI side panels
    Increased text size, added holes for the corners, added schematic title bloc plus misc. changes
    [Module17-Side_Panels_Back.kicad_pcb, Module17-Side_Panels_Back.kicad_sch, Module17-Side_Panels_Front.kicad_pcb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]
2024-01-11 Updated HMI top panel
    Removed soldermask on the edges, added some vias, updated LED footprints plus misc. changes
    [Module17-HMI.kicad_pcb]
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2024-02-21 Updated mainboard
    Fixed dimension issues: moved some connectors closer to the edge of the board. Made the board 3.3mm longer.
    Added pull-ups to the I2C bus.
    [Audio.kicad_sch, Module17-Mainboard.kicad_pcb, Module17-Mainboard.kicad_sch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]
2024-02-21 Updated HMI board
    Fixed OLED screen power supply (VCC/VDD swapped).
    Fixed Mainboard connector pinout.
    Widened board.
    [Module17-HMI.kicad_pcb, Module17-HMI.kicad_sch]
2024-03-28 Fixed power button Q2 connected in reverse
    [Module17-HMI.kicad_pcb, Module17-HMI.kicad_sch]
2024-04-24 Updated mainboard
    Replaced OHIS speaker resistors with larger 100 ohms resistors
    [Audio.kicad_sch, Module17-Mainboard.kicad_pcb, Module17-Mainboard.kicad_sch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]
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2024-06-07 Added polarity on RTC battery connector
    Added polarity marking on sikscreen layer.
    [Module17-Mainboard.kicad_pcb]
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2024-06-30 Fixed missing symbol
    Barrel polarity symbol was missing. No electrical or functional changes.
    [Module17-Mainboard.kicad_pcb, Module17-Side_Panels_Back.kicad_pcb]
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
